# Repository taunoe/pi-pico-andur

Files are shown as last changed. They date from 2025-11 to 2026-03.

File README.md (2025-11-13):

# Pi Pico Andur

## Proto 0

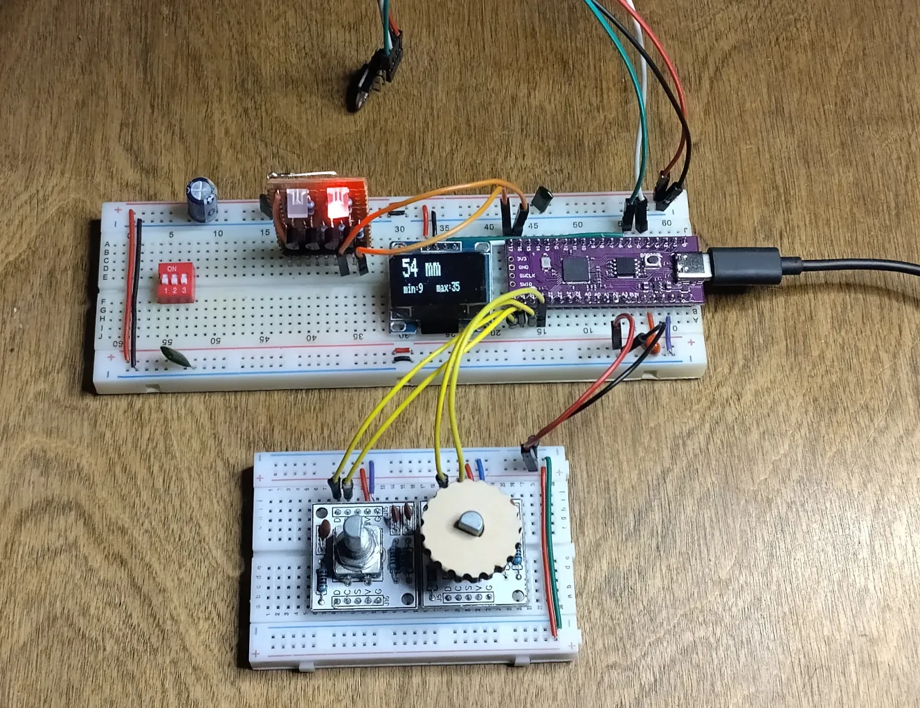
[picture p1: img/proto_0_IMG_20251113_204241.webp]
Pilt proto 0


- https://www.instagram.com/reel/DPMSu_giLpH/?utm_source=ig_web_copy_link&igsh=MzRlODBiNWFlZA==
- https://www.instagram.com/reel/DPefCeejA3R/?utm_source=ig_web_copy_link&igsh=MzRlODBiNWFlZA==

## Proto 1 Jupid

Pilt|Nimi    | m    | m   |Kood
----|--------|------|-----|----
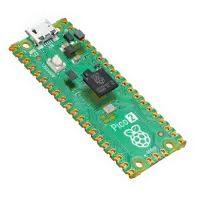
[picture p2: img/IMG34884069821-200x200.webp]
|RASPBERRY PI PICO 2| Cortex-M33| |SC1631
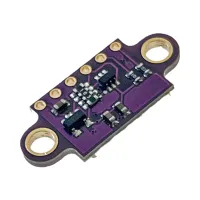
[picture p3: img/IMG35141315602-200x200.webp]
|ToF / Laser moodul| VL53L0X 3-5VDC| I2C, 0.05÷1.2m | OKYN220420-17
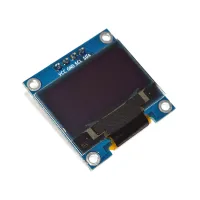
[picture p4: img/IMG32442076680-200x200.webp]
|OLED display| 0.96''| Sinine ja valge| OKY4020
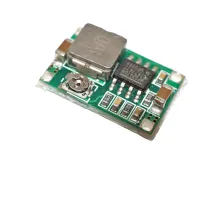
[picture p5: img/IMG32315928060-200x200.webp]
|Toitemoodul DC/DC| step-down |4.75..23V/1..17 3A|OKY3504-1
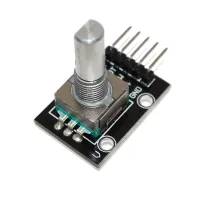
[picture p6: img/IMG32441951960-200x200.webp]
|Rotary Encoder|-|-| OKY3431
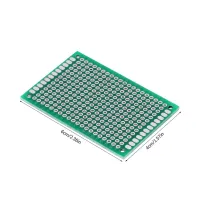
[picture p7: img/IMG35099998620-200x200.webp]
|Makettplaat| 40*60mm |-|OKY0001-1-4X6CM
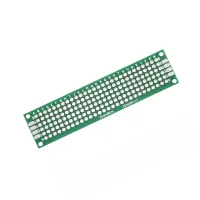
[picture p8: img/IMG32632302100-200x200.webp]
|Makettplaat| 20*80mm| kahepoolne| OKN426-8
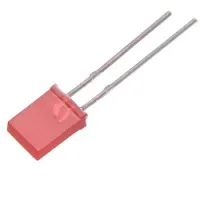
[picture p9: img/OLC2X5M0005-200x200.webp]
|LED punane matt| 2*5mm| 5mcd| OLC2X5M0005
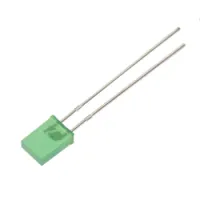
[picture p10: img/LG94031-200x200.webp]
|LED roheline matt| 2*5mm| 10mcd| LZ2X5M0010
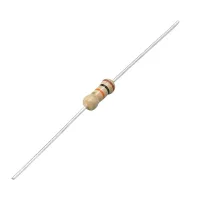
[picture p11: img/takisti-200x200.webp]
|Takisti | 470R | 1/4W| -
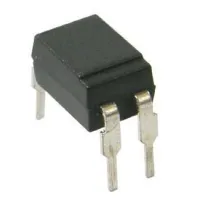
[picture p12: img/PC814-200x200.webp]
|Optron|EL817C |-| PC817
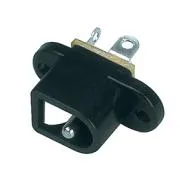
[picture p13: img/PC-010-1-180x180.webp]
|Toitepesa paneelile| 2.1/5.5mm| | PC-010
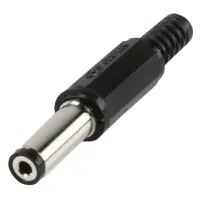
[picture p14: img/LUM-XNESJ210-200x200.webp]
|Pistik| 2.1/5.5mm| 14mm, plast| LUM-XNESJ210
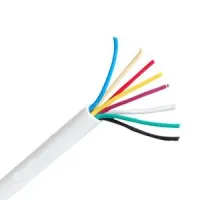
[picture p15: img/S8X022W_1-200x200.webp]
|Signalisatsioonikaabel|8x0.22mm2 |tinatatud Valge|S8X022W
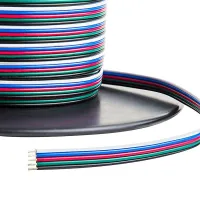
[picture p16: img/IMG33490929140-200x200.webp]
|Lintkaabel| 5*0.3mm2|-| LP05-RGBW
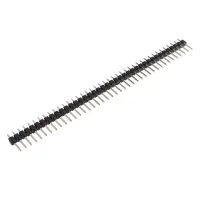
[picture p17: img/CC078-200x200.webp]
|Piikriba |1*40pin| 2.54mm|CC078
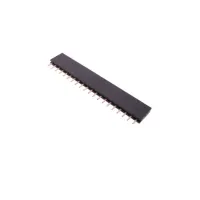
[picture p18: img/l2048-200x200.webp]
|Piikriba pesa plaadile| 1*20pin |2.54mm |L20420GS
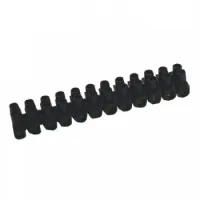
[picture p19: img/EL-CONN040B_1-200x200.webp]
|Kruviklemmliist| 12*2.5mm2| STCM-8471| EL-CONN040B
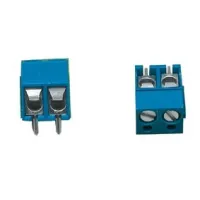
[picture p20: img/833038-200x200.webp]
|2-ne klemmliist pcb| 5.0mm| h=10mm 1.5mm2| TB-001LC
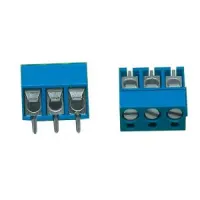
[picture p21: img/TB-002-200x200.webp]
|3-ne klemmiist. pcb| 5.0mm| h=12mm| TB-002
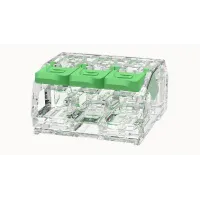
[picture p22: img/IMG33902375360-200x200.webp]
|Ühendusklemm 3-ne| kangiga avatav ja suletav|-| DGBSC-SG01/4-03P
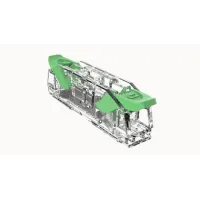
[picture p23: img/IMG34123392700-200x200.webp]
|Ühendusklemm 2-ne| kangiga| läbiv|DGBSC-SG02/4-01P
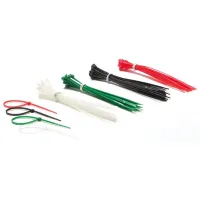
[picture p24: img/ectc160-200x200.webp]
|Kaablisideme komplekt| 160mm| Värvilised| ECTC160

Tauno Erik 2025

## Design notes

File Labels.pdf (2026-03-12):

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
GPIO1
XSHUT

VIN

SDA
SCL

GND

GPIO1

XSHUT

VIN

SDA
SCL

GND

GPIO1

XSHUT

VIN

SDA
SCL

GND

GPIO1

XSHUT

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
## SDA SCL GND VCC

Signal OUT | Sensor
| Sensor
| Sensor

+24V in

Signal OUT +24V in

Signal OUT

VCC

GND

SCL

SDA

+24V in

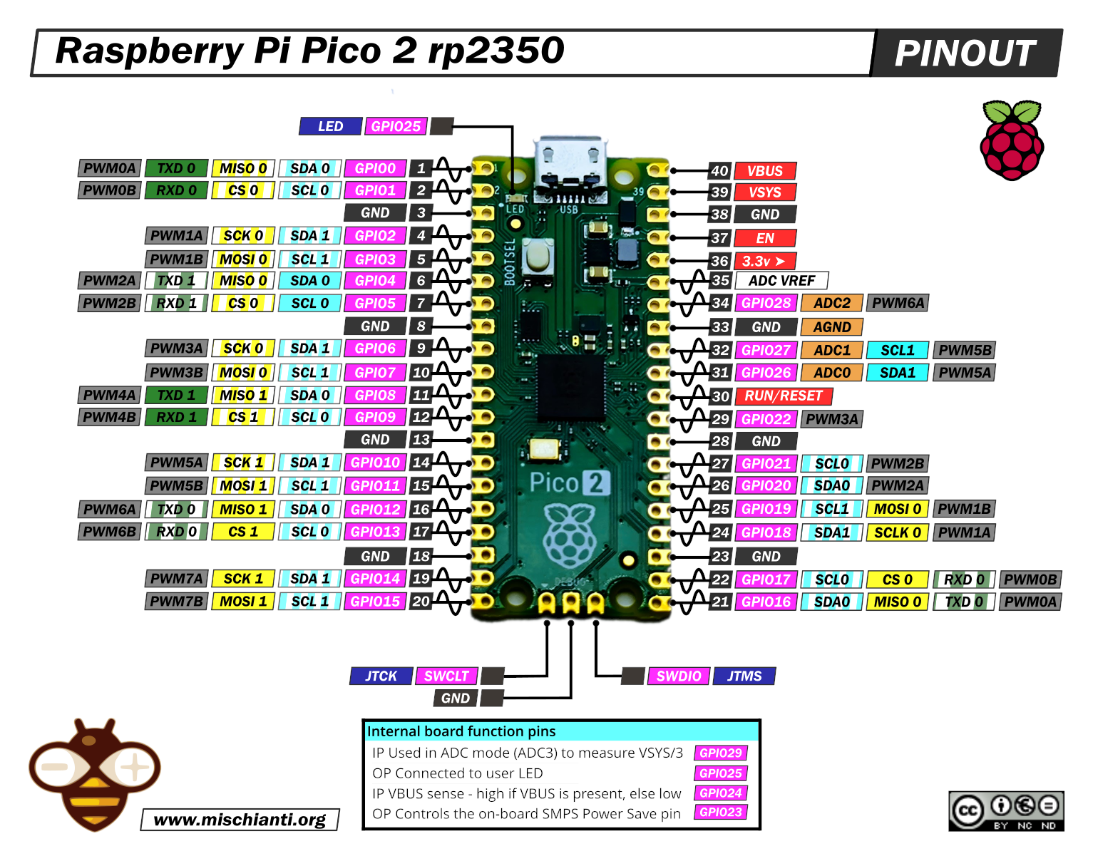
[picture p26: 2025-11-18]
datasheets/Raspberry-Pi-Pico-2-rp2350-pinout-mischianti.png

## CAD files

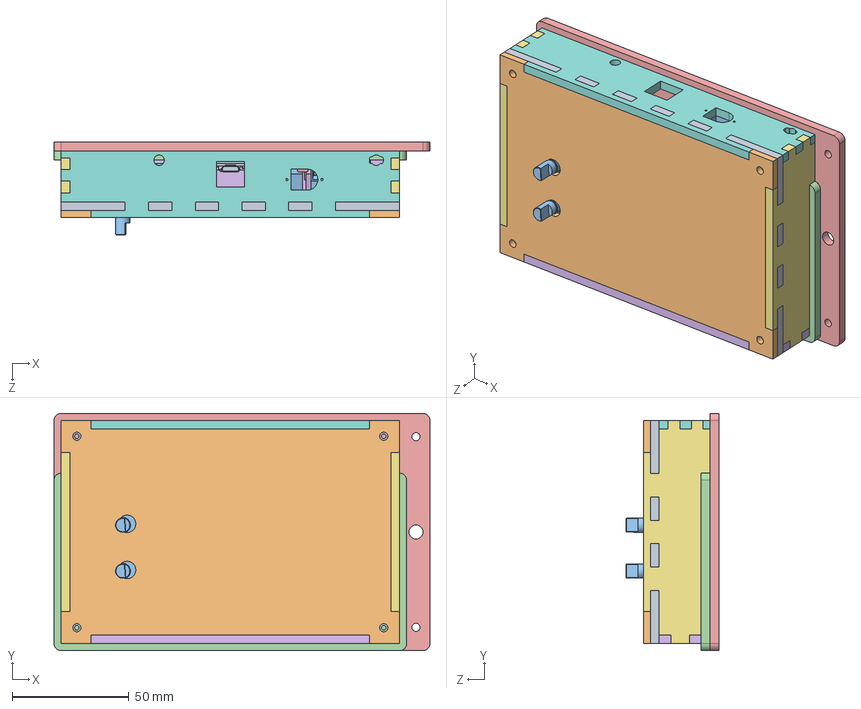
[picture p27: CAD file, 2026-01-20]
3d_models/v2_3.8mm/KOOS_v2.SLDASM
161.0 x 101.6 x 39.8 mm
RaspberryPi_Pico_W_Module_KiCad^RaspberryPi_Pico_W_pcb_KOOS_v2
D_DO-41_SOD81_P10.16mm_Horizontal^pcb_KOOS_v2 x 2
TerminalBlock_Phoenix_MKDS-1,5-2_1x02_P5.00mm_Horizontal^pcb_KOOS_v2 x 4
R_Axial_DIN0207_L6.3mm_D2.5mm_P10.16mm_Horizontal^pcb_KOOS_v2 x 6
DIP-4_W7.62mm^pcb_KOOS_v2 x 2
TerminalBlock_Phoenix_MKDS-1,5-3_1x03_P5.00mm_Horizontal^pcb_KOOS_v2 x 7
LED_Rectangular_W5.0mm_H2.0mm^pcb_KOOS_v2 x 2
TerminalBlock_Phoenix_PT-1,5-6-5.0-H_1x06_P5.00mm_Horizontal^pcb_KOOS_v2
pcb_PCB^pcb_KOOS_v2
OLED_IIC_096^KOOS_v2
Rotary-Encoder^KOOS_v2 x 2
v2_alusraam
v2_põhi
v2_külg_pikem
v2_külg_lühem x 2
v2_ülemine_raam
v2_pleks
v2_power_raam

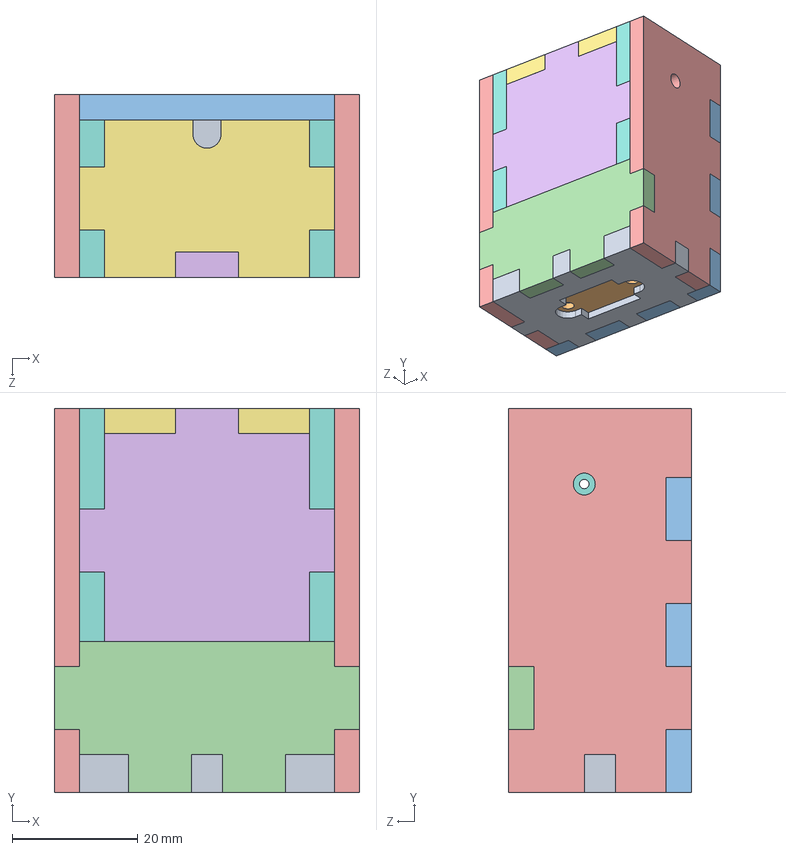
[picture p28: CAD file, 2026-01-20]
3d_models/v2_3.8mm/anduri_karp/v2_Anduri_karp.SLDASM
48.5 x 61.0 x 29.0 mm
v2_andur_esi
v2_andur_tof
v2_andur_alumine
v2_andur_pealmine
v2_andur_külg x 2
v2_andur_kaane_lagi
v2_andur_kaane_juhtmeauk
v2_andur_kaane_külg x 2

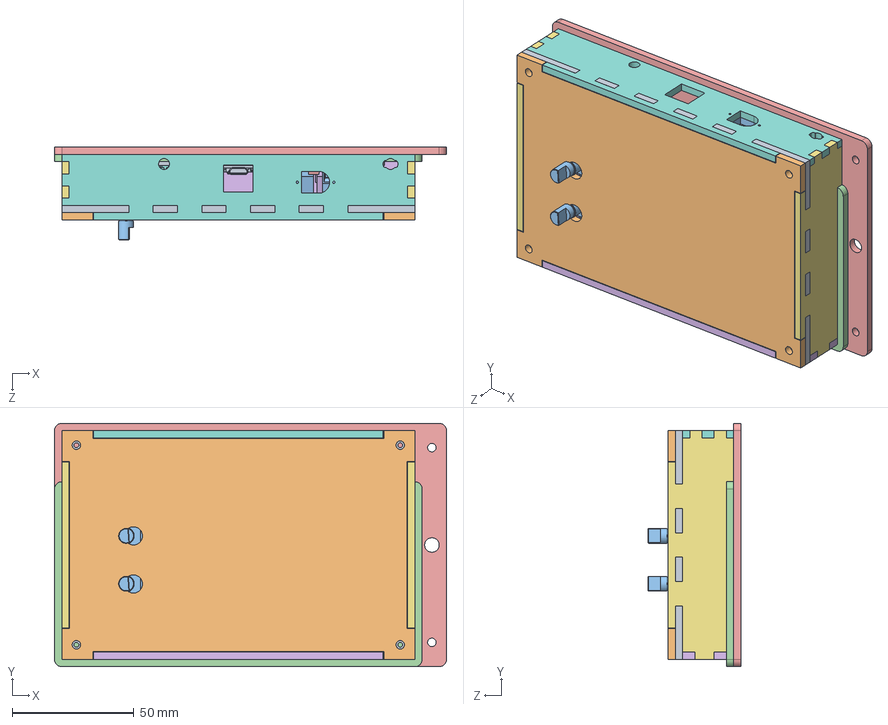
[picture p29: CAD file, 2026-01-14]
3d_models/v2/KOOS_v2.SLDASM
161.0 x 100.0 x 38.2 mm
RaspberryPi_Pico_W_Module_KiCad^RaspberryPi_Pico_W_pcb_KOOS_v2
D_DO-41_SOD81_P10.16mm_Horizontal^pcb_KOOS_v2 x 2
TerminalBlock_Phoenix_MKDS-1,5-2_1x02_P5.00mm_Horizontal^pcb_KOOS_v2 x 4
R_Axial_DIN0207_L6.3mm_D2.5mm_P10.16mm_Horizontal^pcb_KOOS_v2 x 6
DIP-4_W7.62mm^pcb_KOOS_v2 x 2
TerminalBlock_Phoenix_MKDS-1,5-3_1x03_P5.00mm_Horizontal^pcb_KOOS_v2 x 7
LED_Rectangular_W5.0mm_H2.0mm^pcb_KOOS_v2 x 2
TerminalBlock_Phoenix_PT-1,5-6-5.0-H_1x06_P5.00mm_Horizontal^pcb_KOOS_v2
pcb_PCB^pcb_KOOS_v2
OLED_IIC_096^KOOS_v2
Rotary-Encoder^KOOS_v2 x 2
v2_alusraam
v2_põhi
v2_külg_pikem
v2_külg_lühem x 2
v2_külg_pikem_avadega
v2_ülemine_raam
v2_pleks
v2_power_raam

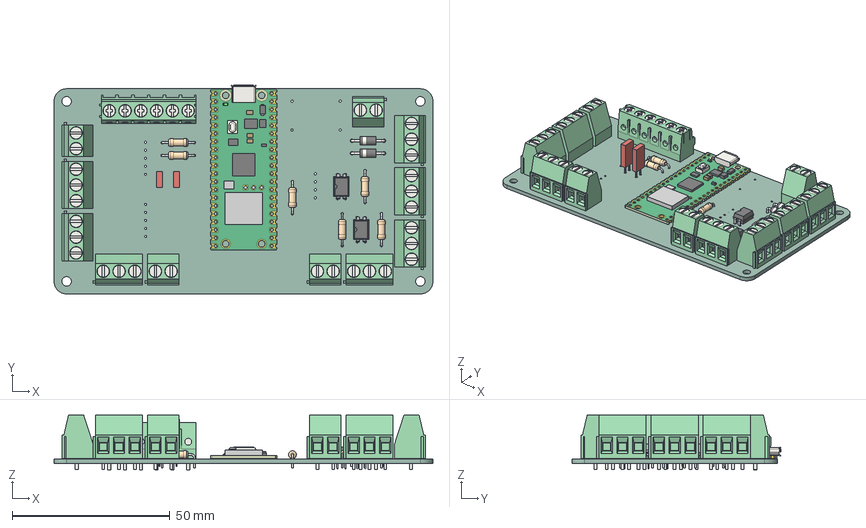
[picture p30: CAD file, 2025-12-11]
3d_models/pcb.step
120.0 x 66.2 x 17.4 mm
D_DO-41_SOD81_P10.16mm_Horizontal x 2
TerminalBlock_Phoenix_MKDS-1,5-2_1x02_P5.00mm_Horizontal x 4
R_Axial_DIN0207_L6.3mm_D2.5mm_P10.16mm_Horizontal x 6
DIP-4_W7.62mm x 2
TerminalBlock_Phoenix_MKDS-1,5-3_1x03_P5.00mm_Horizontal x 7
RaspberryPi_Pico_W_Module_KiCad
LED_Rectangular_W5.0mm_H2.0mm x 2
TerminalBlock_Phoenix_PT-1,5-6-5.0-H_1x06_P5.00mm_Horizontal
pcb_PCB

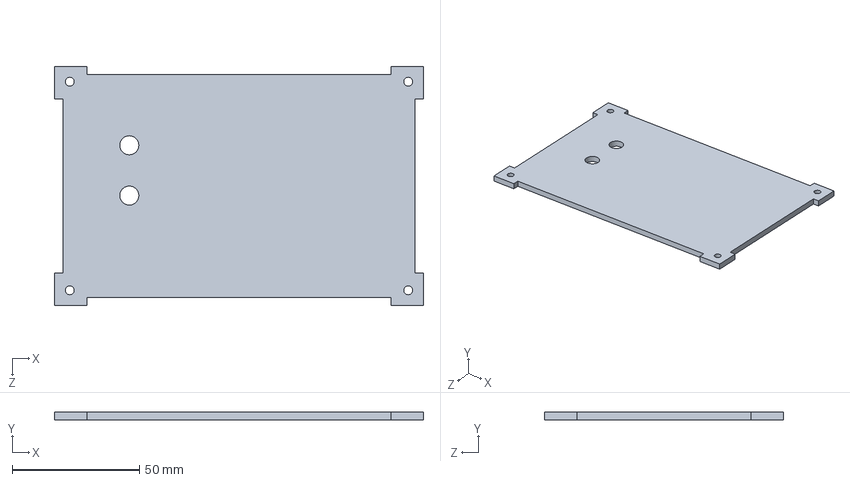
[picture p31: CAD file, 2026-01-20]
3d_models/v2/v2_pleks.SLDPRT
145.0 x 3.00 x 94.0 mm

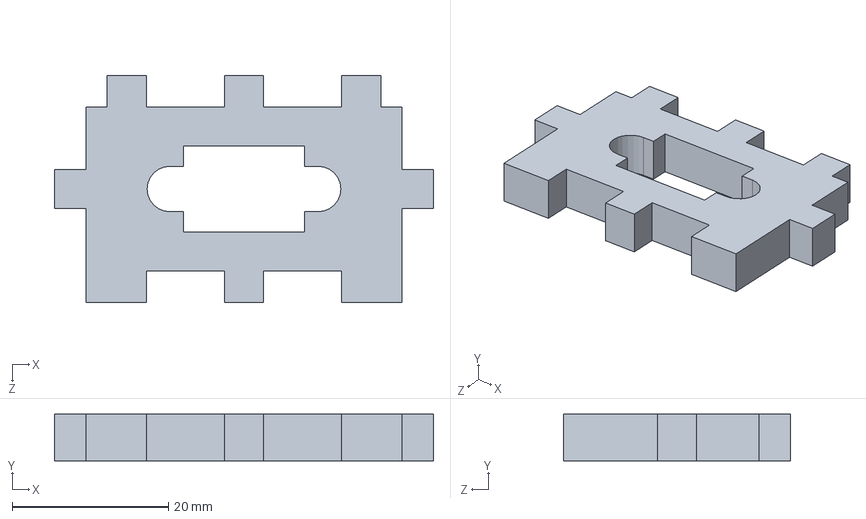
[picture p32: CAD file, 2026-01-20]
3d_models/v2_3.8mm/anduri_karp/v2_andur_esi.SLDPRT
48.5 x 6.00 x 29.0 mm

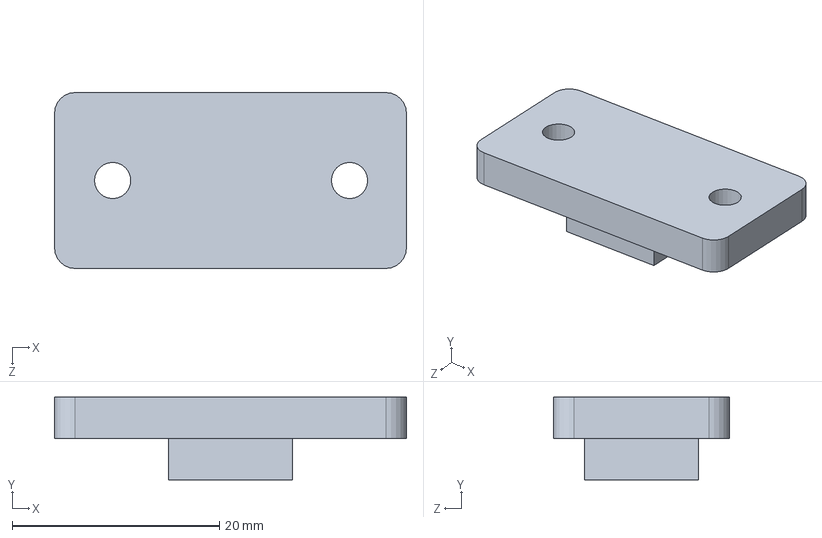
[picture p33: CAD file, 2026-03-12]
3d_models/v2_3.8mm/v2_usb_kork.SLDPRT
34.0 x 8.00 x 17.0 mm

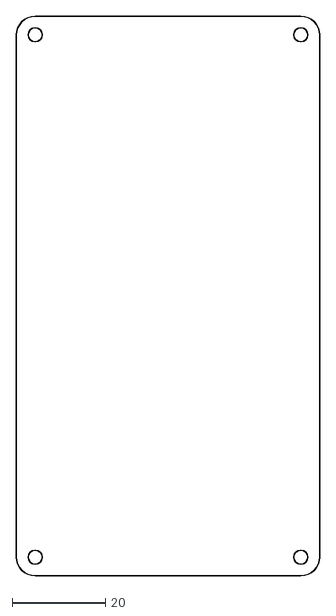
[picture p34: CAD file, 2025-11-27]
KiCad/pcb/piirjoon.dxf
65.0 x 120.0

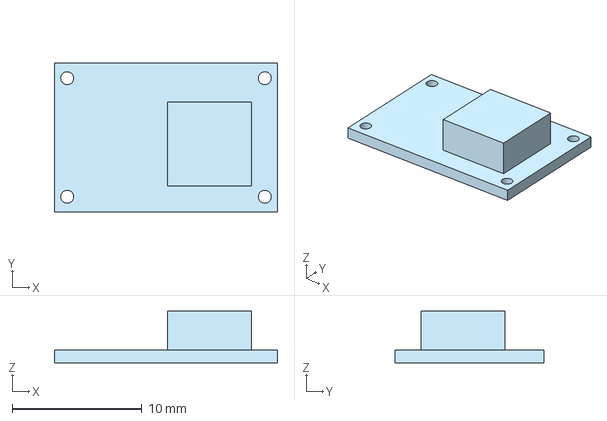
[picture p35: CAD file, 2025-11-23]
3d_models/power.step
17.2 x 11.5 x 4.00 mm

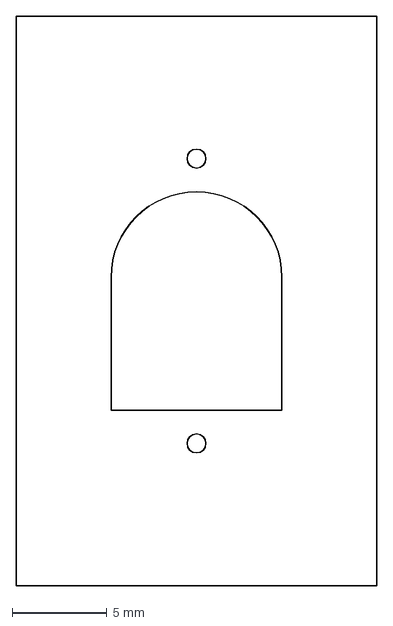
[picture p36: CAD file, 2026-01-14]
3d_models/v2/v2_power_raam.DXF
19.0 x 30.0 mm

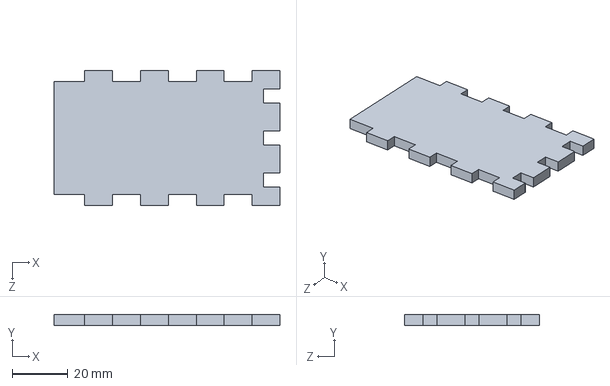
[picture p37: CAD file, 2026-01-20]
3d_models/v2_3.8mm/anduri_karp/v2_andur_alumine.SLDPRT
81.0 x 4.00 x 48.5 mm

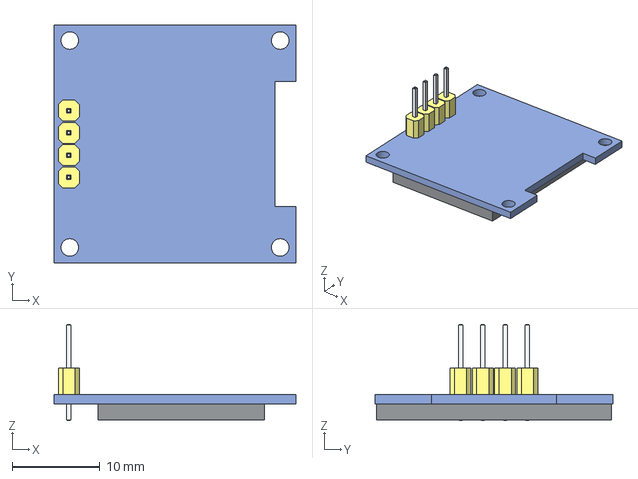
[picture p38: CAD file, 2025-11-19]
3d_models/OLED_IIC_096.step
27.6 x 27.2 x 11.0 mm

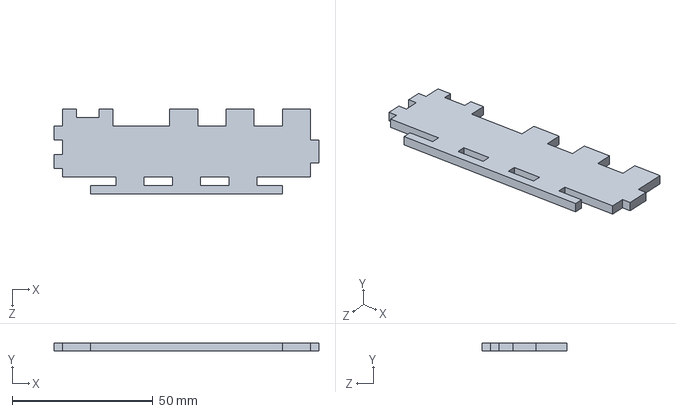
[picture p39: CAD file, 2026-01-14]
3d_models/v2/v2_külg_lühem.SLDPRT
94.0 x 3.00 x 30.0 mm

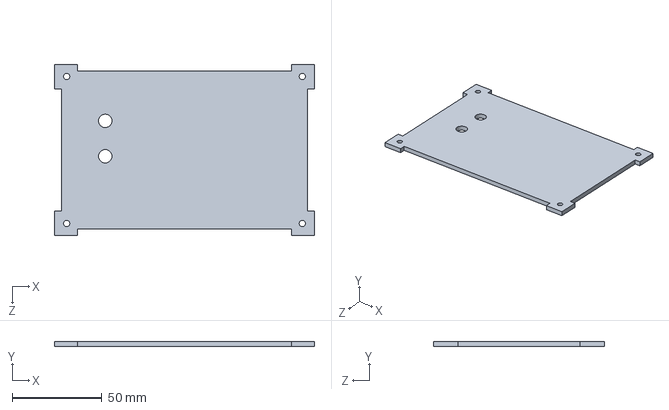
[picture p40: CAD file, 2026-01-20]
3d_models/v2_3.8mm/v2_pleks.SLDPRT
145.0 x 3.00 x 95.6 mm

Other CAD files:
3d_models/Rotary-Encoder.step
3d_models/v2/v2_ülemine_raam.SLDPRT
3d_models/v2_3.8mm/anduri_karp/v2_andur_tof.SLDPRT
3d_models/v2_3.8mm/v2_põhi.SLDPRT
3d_models/v1/Anduri_karp.SLDASM
3d_models/v1/KOOS.SLDASM
3d_models/v1/PCB.DXF
3d_models/v1/andur_alumine.DXF
3d_models/v1/andur_alumine.SLDPRT
3d_models/v1/andur_esi.DXF
3d_models/v1/andur_esi.SLDPRT
3d_models/v1/andur_kaane_juhtmeauk.DXF
3d_models/v1/andur_kaane_juhtmeauk.SLDPRT
3d_models/v1/andur_kaane_külg.DXF
3d_models/v1/andur_kaane_külg.SLDPRT
3d_models/v1/andur_kaane_lagi.DXF
3d_models/v1/andur_kaane_lagi.SLDPRT
3d_models/v1/andur_külg.DXF
3d_models/v1/andur_külg.SLDPRT
3d_models/v1/andur_pealmine.DXF
3d_models/v1/andur_pealmine.SLDPRT
3d_models/v1/andur_tof.SLDPRT
3d_models/v1/ekraani_kinnitus_1.DXF
3d_models/v1/ekraani_kinnitus_1.SLDPRT
3d_models/v1/hing_1.DXF
3d_models/v1/hing_1.SLDPRT
3d_models/v1/kinnitus_plaat.DXF
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

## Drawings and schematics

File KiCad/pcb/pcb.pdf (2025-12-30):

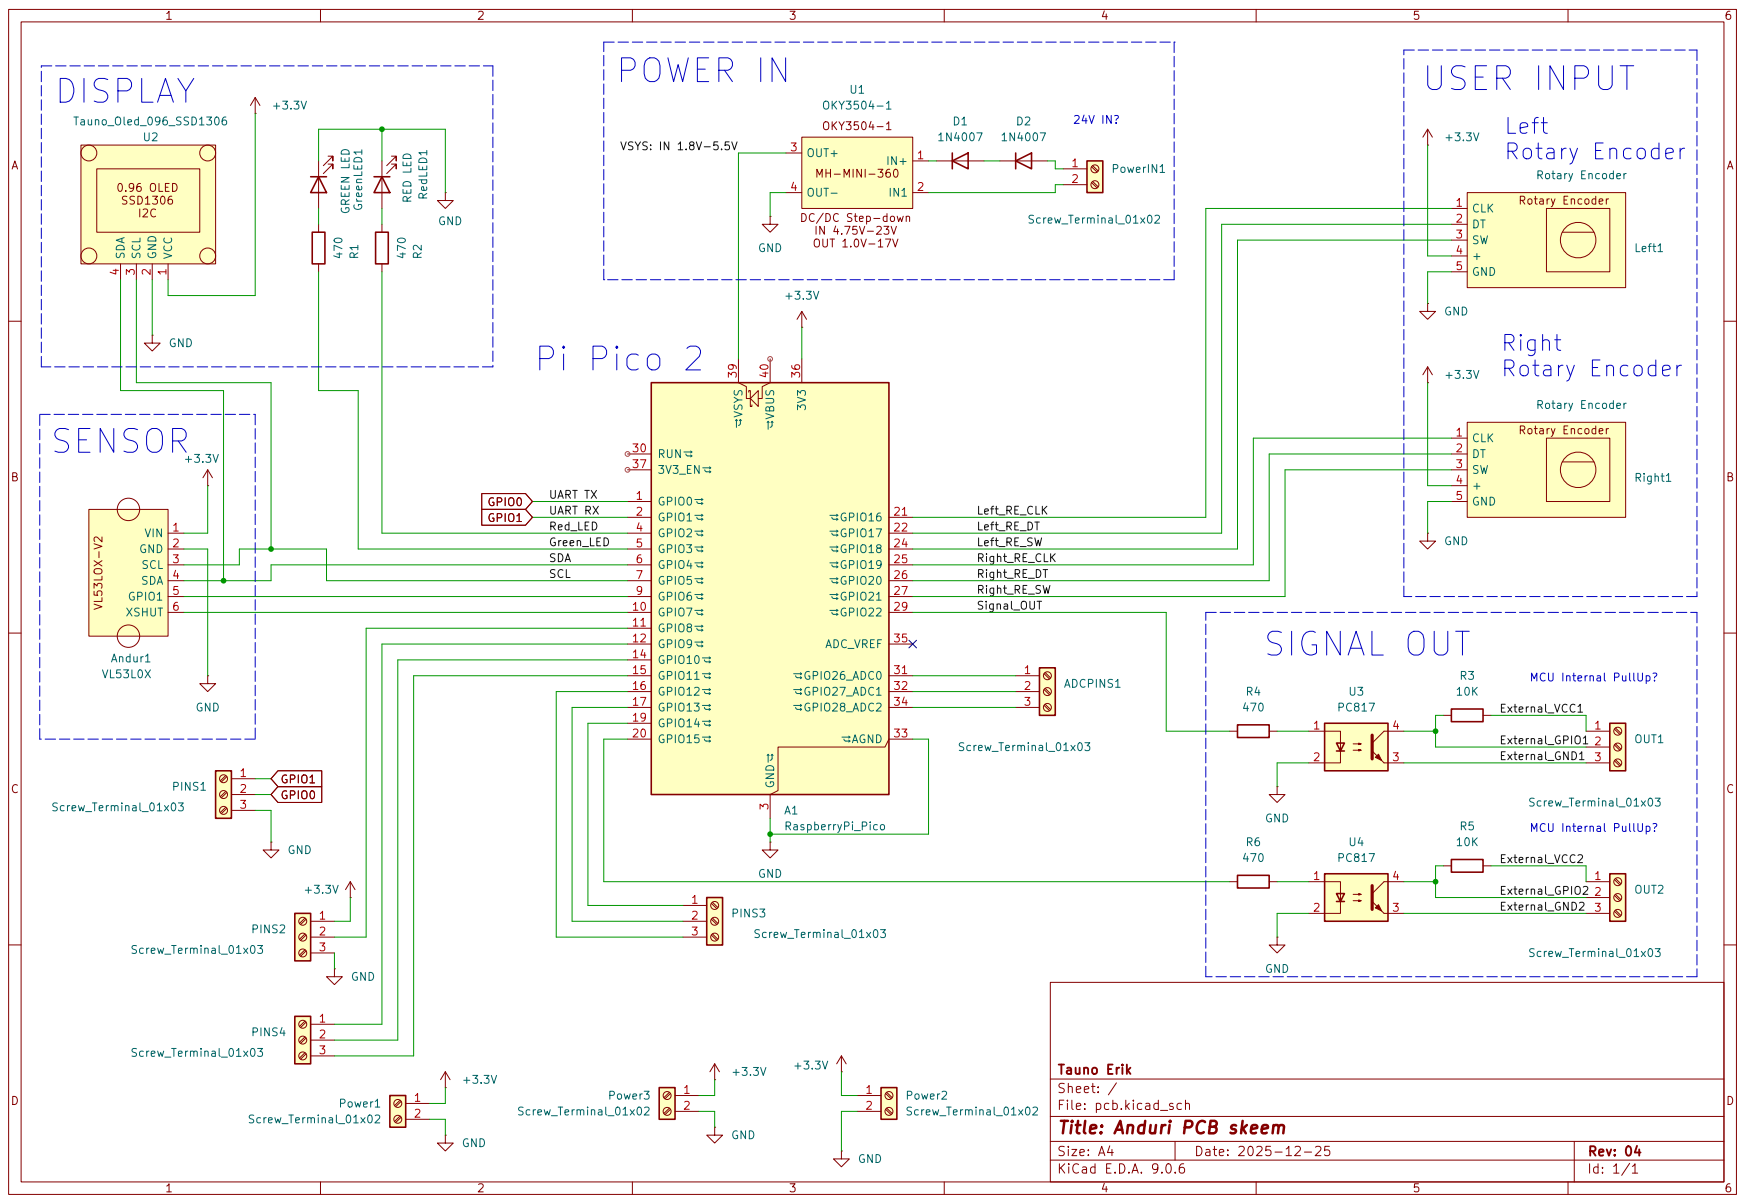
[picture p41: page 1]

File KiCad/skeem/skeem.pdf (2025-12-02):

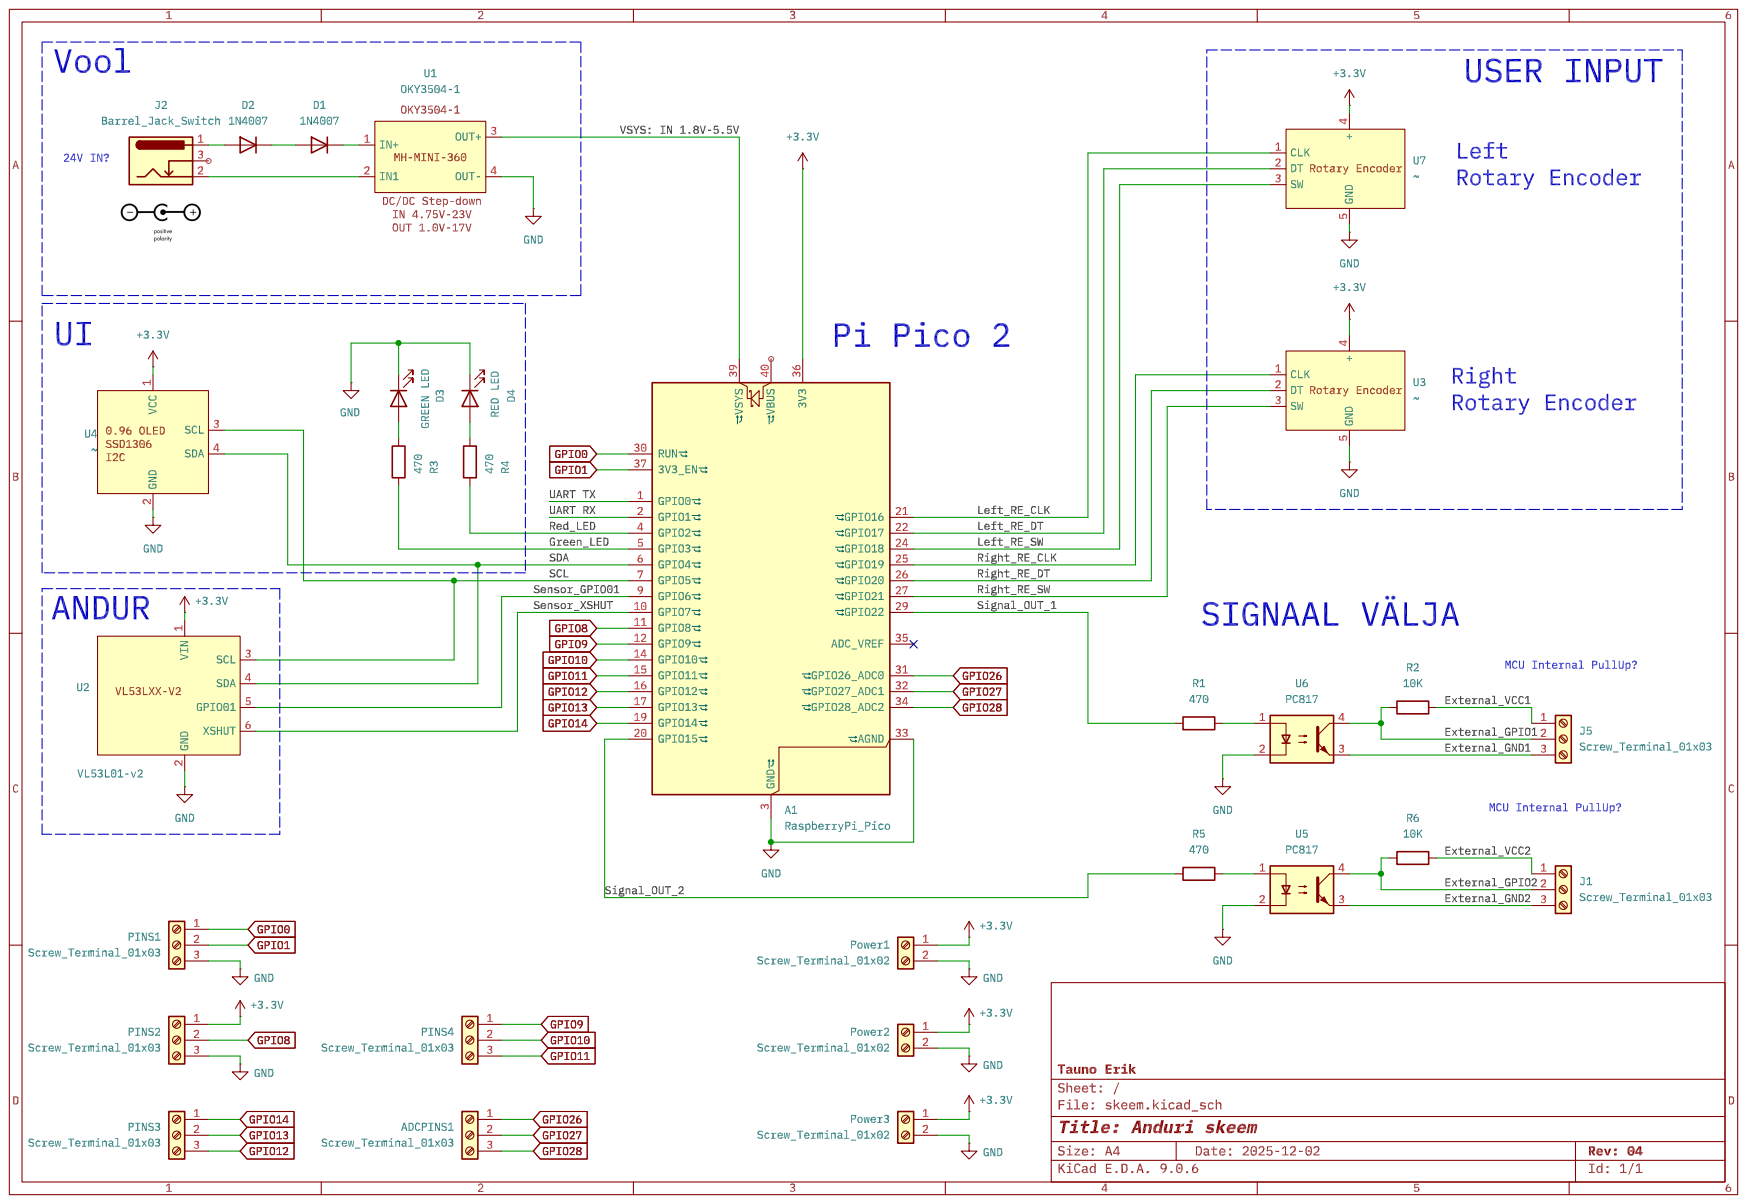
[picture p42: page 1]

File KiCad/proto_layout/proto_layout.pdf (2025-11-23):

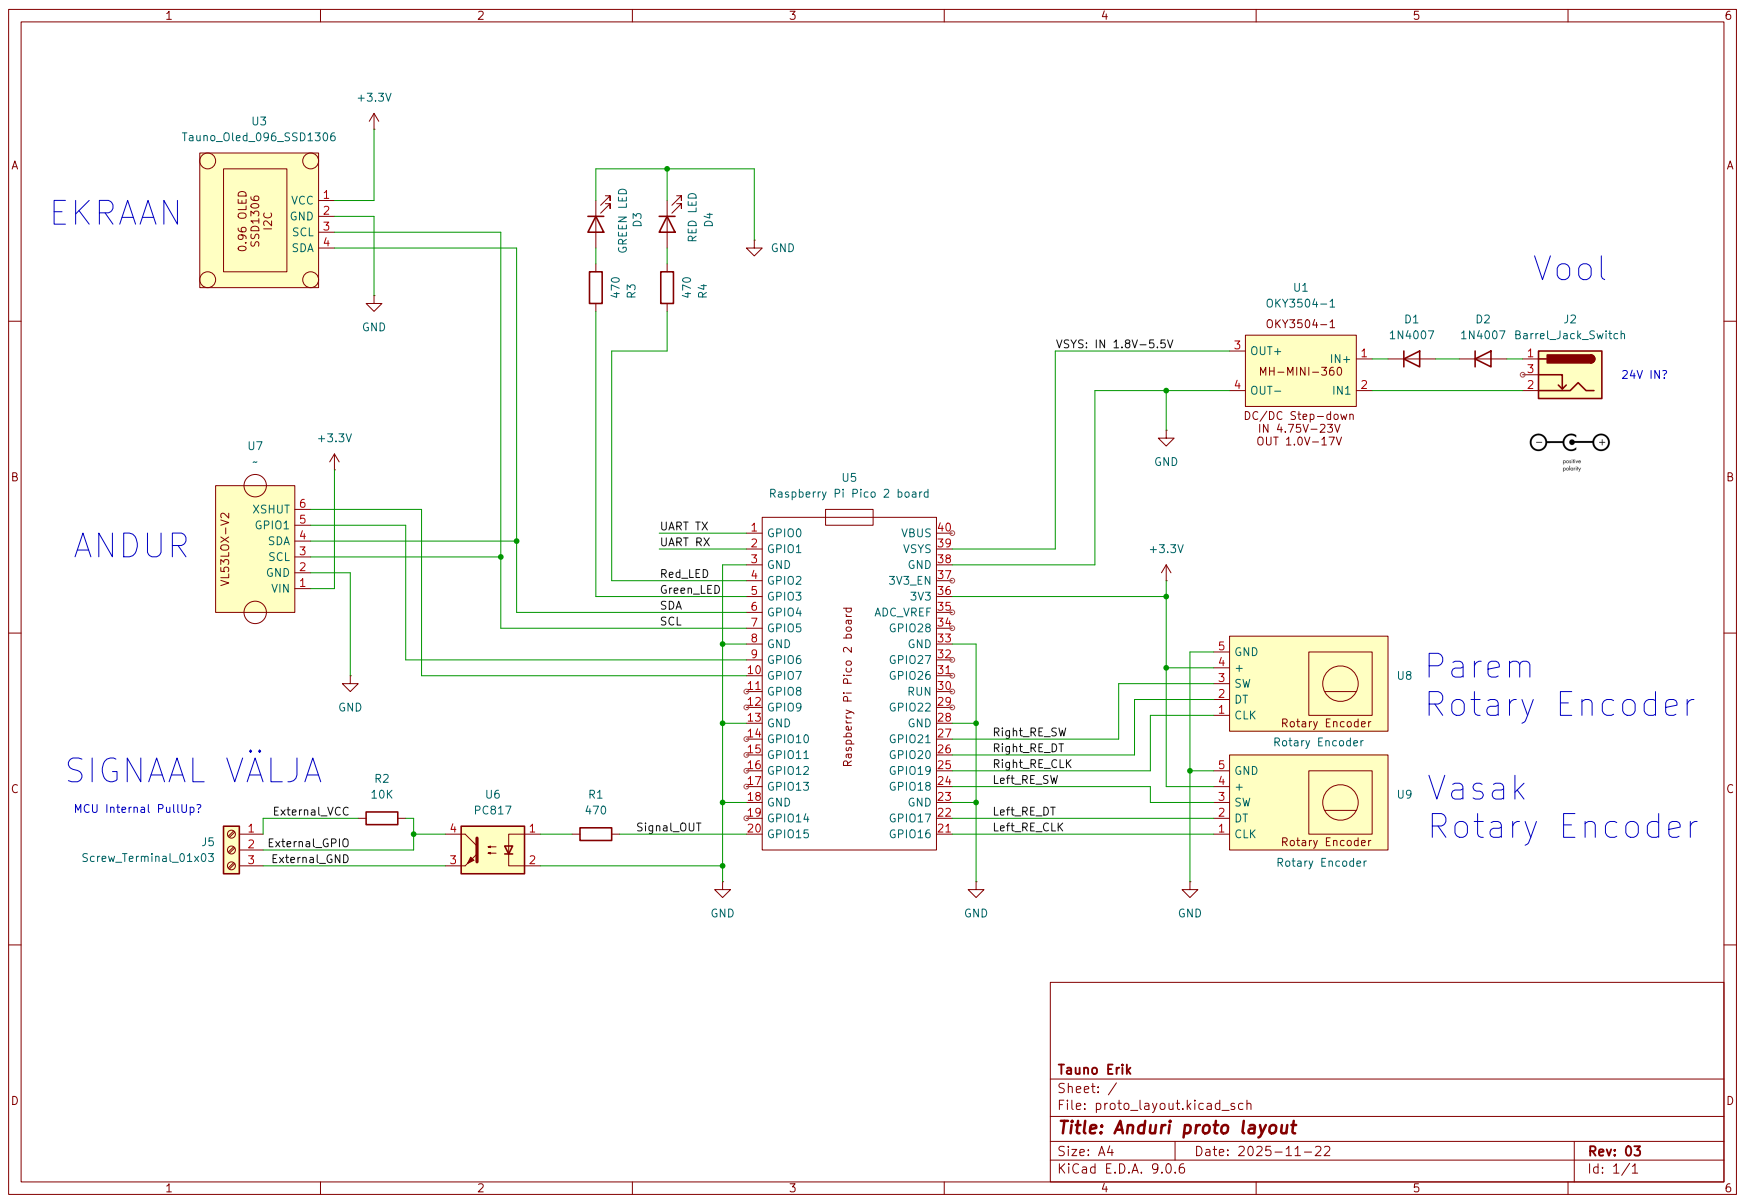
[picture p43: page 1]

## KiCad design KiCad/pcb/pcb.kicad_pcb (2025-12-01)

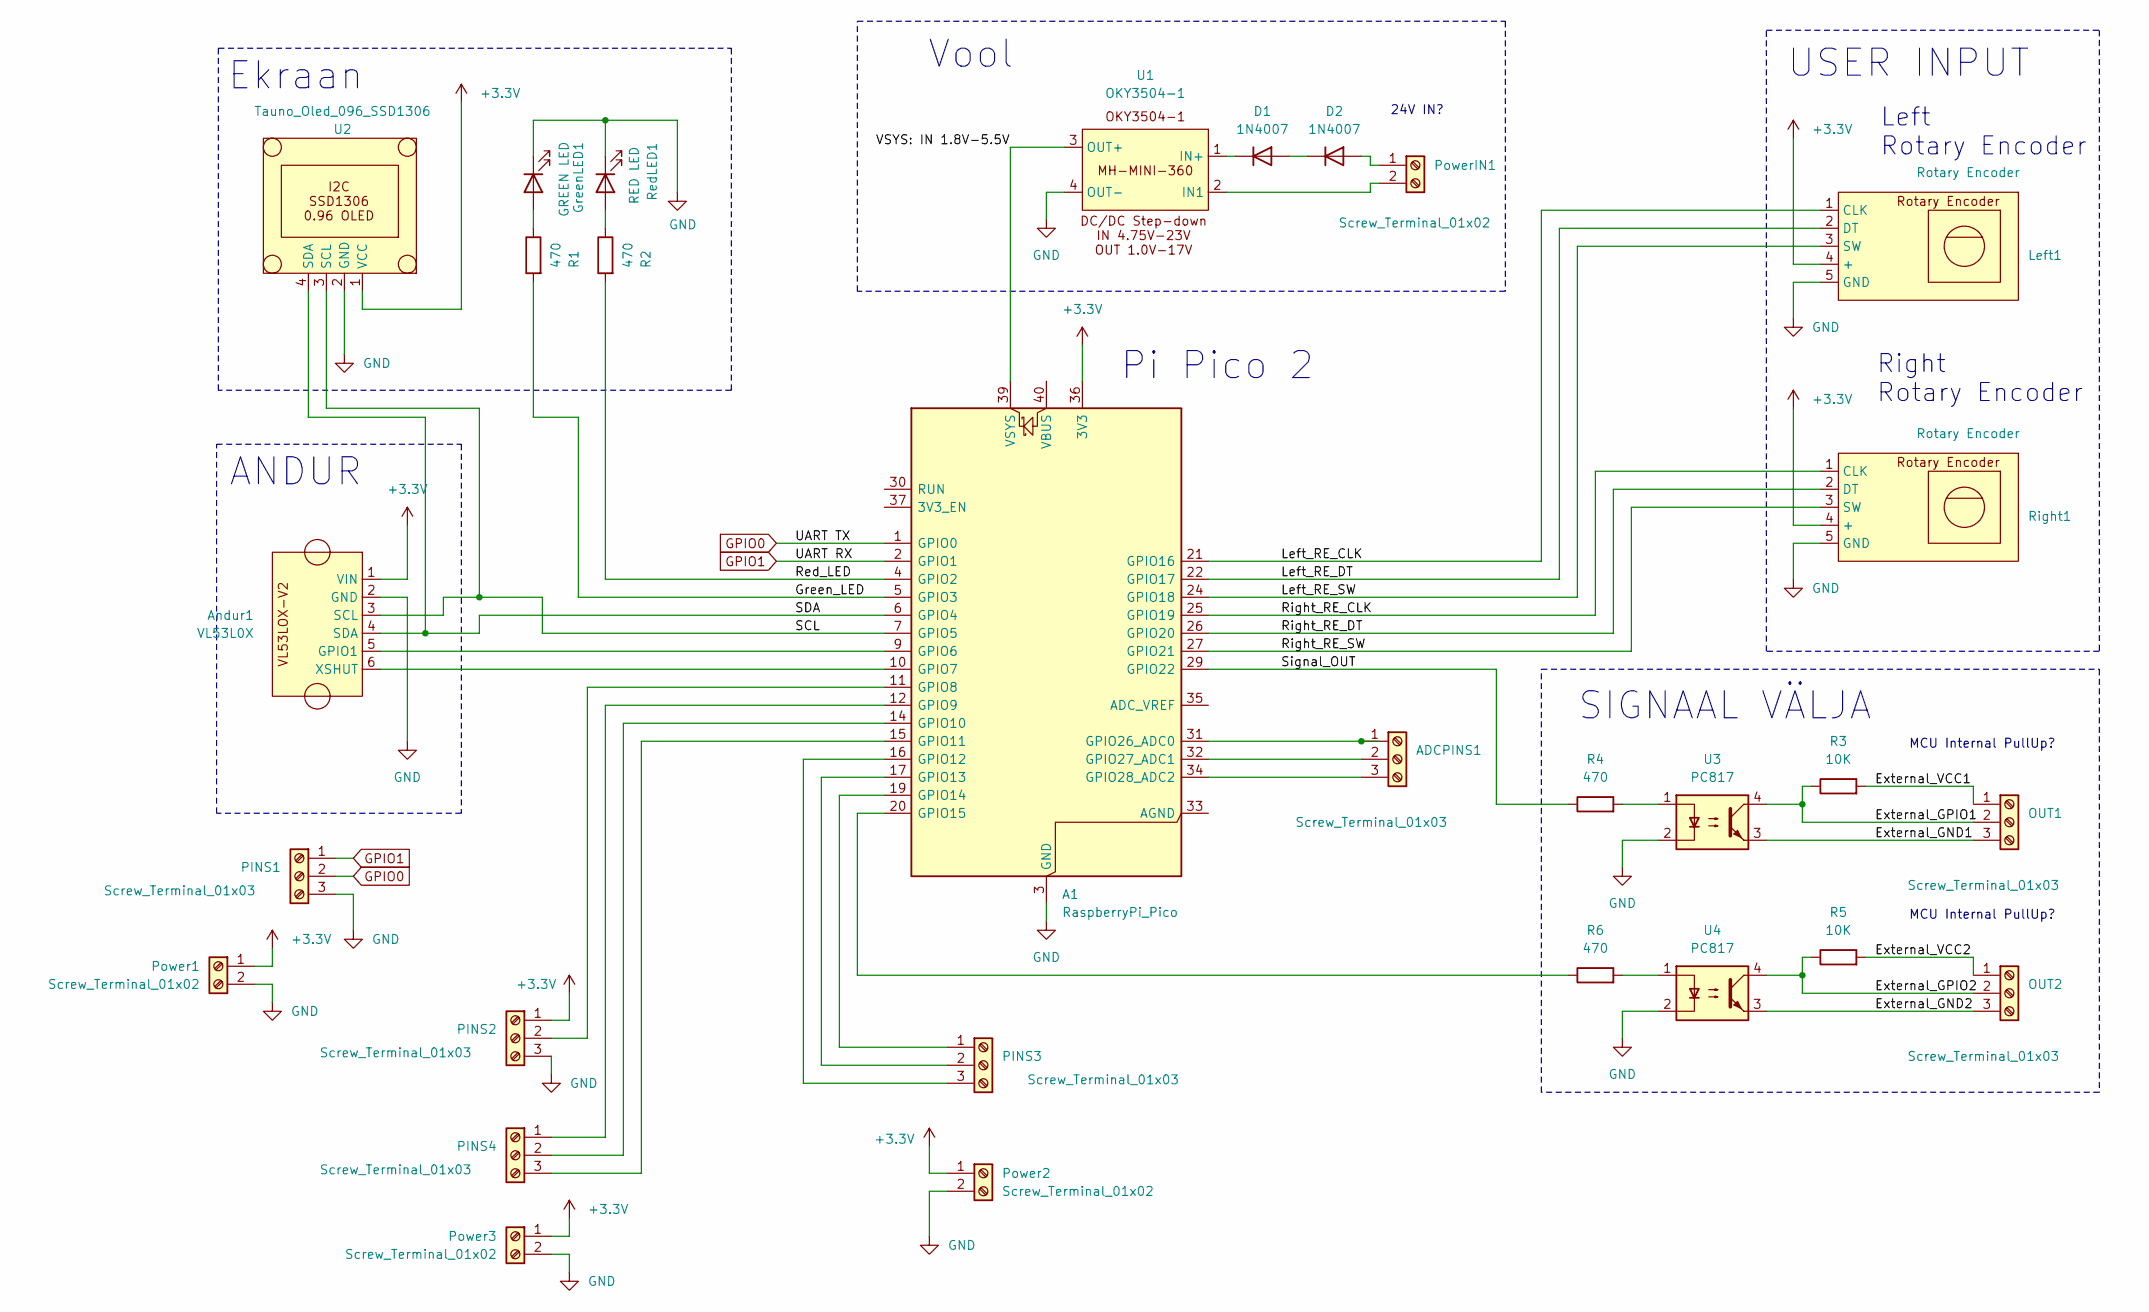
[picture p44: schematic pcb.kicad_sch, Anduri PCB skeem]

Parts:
A1: RaspberryPi_Pico; RaspberryPi_Pico_W_SMD_HandSolder
ADCPINS1: Screw_Terminal_01x03; TerminalBlock_MaiXu_MX126-5.0-03P_1x03_P5.00mm
Andur1: VL53L0X; TerminalBlock_MaiXu_MX126-5.0-06P_1x06_P5.00mm
D1, D2: 1N4007; D_DO-41_SOD81_P10.16mm_Horizontal
GreenLED1: GREEN LED; LED_Rectangular_W5.0mm_H2.0mm
Left1: Rotary Encoder; Tauno_Rotary_Encoder
OUT1, OUT2: Screw_Terminal_01x03; TerminalBlock_MaiXu_MX126-5.0-03P_1x03_P5.00mm
PINS1, PINS2, PINS3, PINS4: Screw_Terminal_01x03; TerminalBlock_MaiXu_MX126-5.0-03P_1x03_P5.00mm
Power1, Power2, Power3: Screw_Terminal_01x02; TerminalBlock_MaiXu_MX126-5.0-02P_1x02_P5.00mm
PowerIN1: Screw_Terminal_01x02; TerminalBlock_MaiXu_MX126-5.0-02P_1x02_P5.00mm
R1, R2, R4, R6: 470; R_Axial_DIN0207_L6.3mm_D2.5mm_P10.16mm_Horizontal
R3, R5: 10K; R_Axial_DIN0207_L6.3mm_D2.5mm_P10.16mm_Horizontal
RedLED1: RED LED; LED_Rectangular_W5.0mm_H2.0mm
Right1: Rotary Encoder; Tauno_Rotary_Encoder
U1: OKY3504-1; Tauno_OKY3504
U2: Tauno_Oled_096_SSD1306; Tauno_OLED_ssd1306
U3, U4: PC817; DIP-4_W7.62mm

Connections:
+3.3V: A1.36 (3V3), Andur1.1 (VIN), Left1.4 (+), PINS2.1, Power1.1, Power2.1, Power3.1, Right1.4 (+), U2.1 (VCC)
/External_GND1: OUT1.3, U3.3
/External_GND2: OUT2.3, U4.3
/External_GPIO1: OUT1.2, R3.1, U3.4
/External_GPIO2: OUT2.2, R5.1, U4.4
/External_VCC1: OUT1.1, R3.2
/External_VCC2: OUT2.1, R5.2
/Green_LED: A1.5 (GPIO3), R1.2
/Left_RE_CLK: A1.21 (GPIO16), Left1.1 (CLK)
/Left_RE_DT: A1.22 (GPIO17), Left1.2 (DT)
/Left_RE_SW: A1.24 (GPIO18), Left1.3 (SW)
/Red_LED: A1.4 (GPIO2), R2.2
/Right_RE_CLK: A1.25 (GPIO19), Right1.1 (CLK)
/Right_RE_DT: A1.26 (GPIO20), Right1.2 (DT)
/Right_RE_SW: A1.27 (GPIO21), Right1.3 (SW)
/SCL: A1.7 (GPIO5), Andur1.3 (SCL), U2.3 (SCL)
/SDA: A1.6 (GPIO4), Andur1.4 (SDA), U2.4 (SDA)
/Signal_OUT: A1.29 (GPIO22), R4.1
/VSYS: IN 1.8V-5.5V: A1.39 (VSYS), U1.3 (OUT+)
GND: A1.3 (GND), A1.8 (GND), A1.13 (GND), A1.18 (GND), A1.23 (GND), A1.28 (GND), A1.38 (GND), Andur1.2 (GND), GreenLED1.1 (K), Left1.5 (GND), PINS1.3, PINS2.3, Power1.2, Power2.2, Power3.2, RedLED1.1 (K), Right1.5 (GND), U1.4 (OUT-), U2.2 (GND), U3.2, U4.2
GPIO0: A1.1 (GPIO0), PINS1.2
GPIO1: A1.2 (GPIO1), PINS1.1
unnamed: A1.9 (GPIO6), Andur1.5 (GPIO1)
unnamed: A1.10 (GPIO7), Andur1.6 (XSHUT)
unnamed: A1.11 (GPIO8), PINS2.2
unnamed: A1.12 (GPIO9), PINS4.1
unnamed: A1.14 (GPIO10), PINS4.2
unnamed: A1.15 (GPIO11), PINS4.3
unnamed: A1.16 (GPIO12), PINS3.3
unnamed: A1.17 (GPIO13), PINS3.2
unnamed: A1.19 (GPIO14), PINS3.1
unnamed: A1.20 (GPIO15), R6.1
unnamed: A1.31 (GPIO26_ADC0), ADCPINS1.1
unnamed: A1.32 (GPIO27_ADC1), ADCPINS1.2
unnamed: A1.34 (GPIO28_ADC2), ADCPINS1.3
unnamed: D1.2 (A), D2.1 (K)
unnamed: D1.1 (K), U1.1 (IN+)
unnamed: D2.2 (A), PowerIN1.1
unnamed: GreenLED1.2 (A), R1.1
unnamed: PowerIN1.2, U1.2 (IN1)
unnamed: R4.2, U3.1
unnamed: R6.2, U4.1
unnamed: R2.1, RedLED1.2 (A)

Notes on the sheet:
Right Rotary Encoder
Ekraan
Vool
ANDUR
MCU Internal PullUp?
Pi Pico 2
SIGNAAL VÄLJA
USER INPUT
24V IN?
Left Rotary Encoder

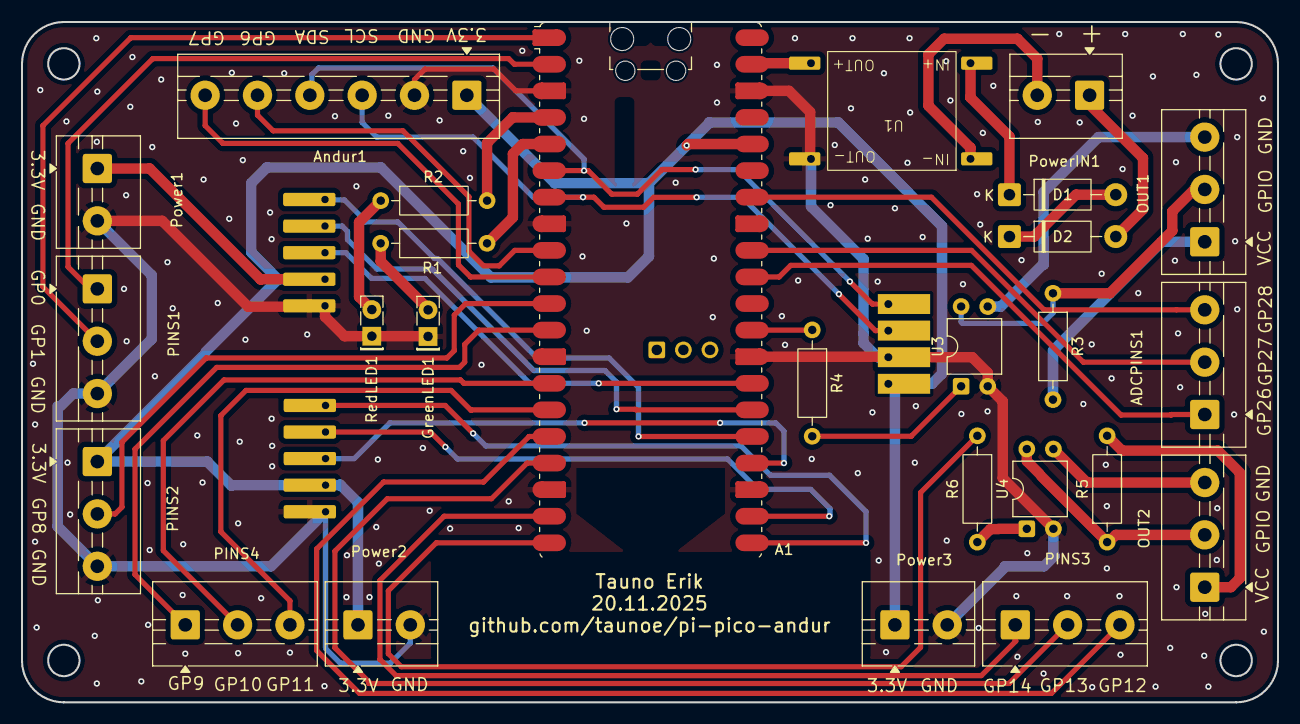
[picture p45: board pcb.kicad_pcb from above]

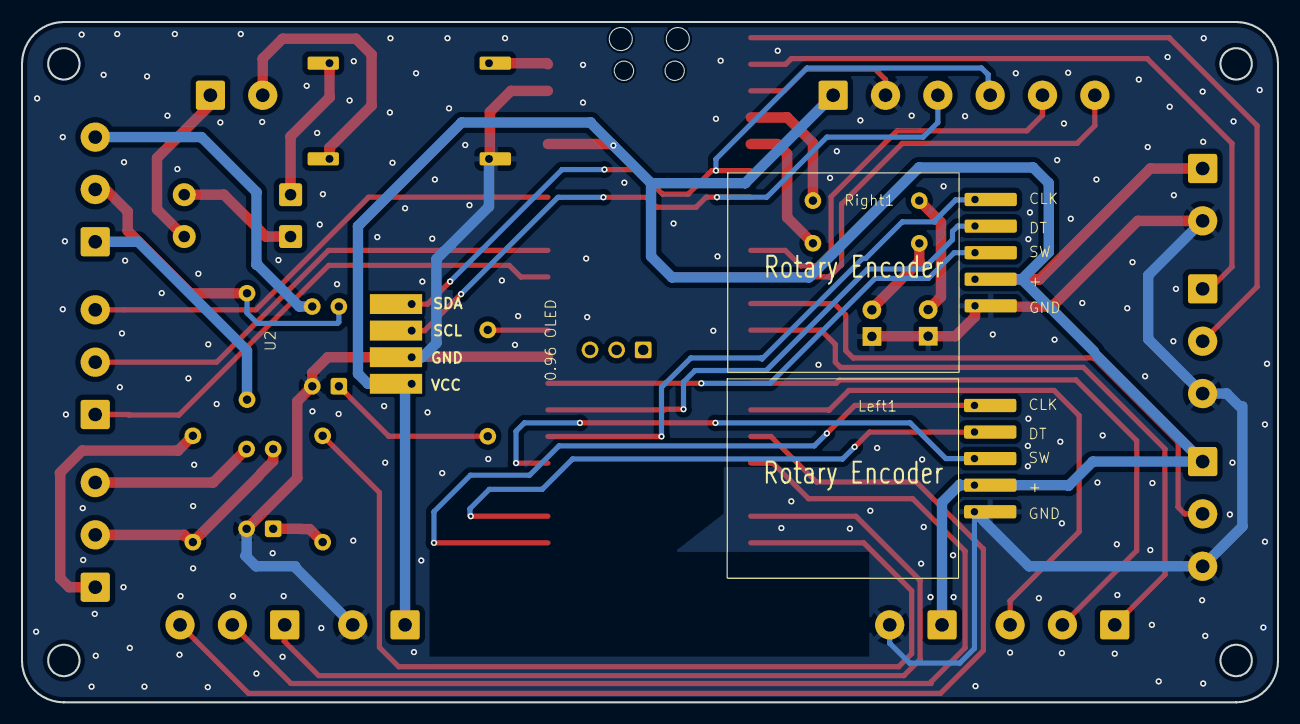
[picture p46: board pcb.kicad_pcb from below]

Board: 2 copper layers, 120.0 x 65.0 mm, 29 parts (3 on the bottom side), 43 nets.

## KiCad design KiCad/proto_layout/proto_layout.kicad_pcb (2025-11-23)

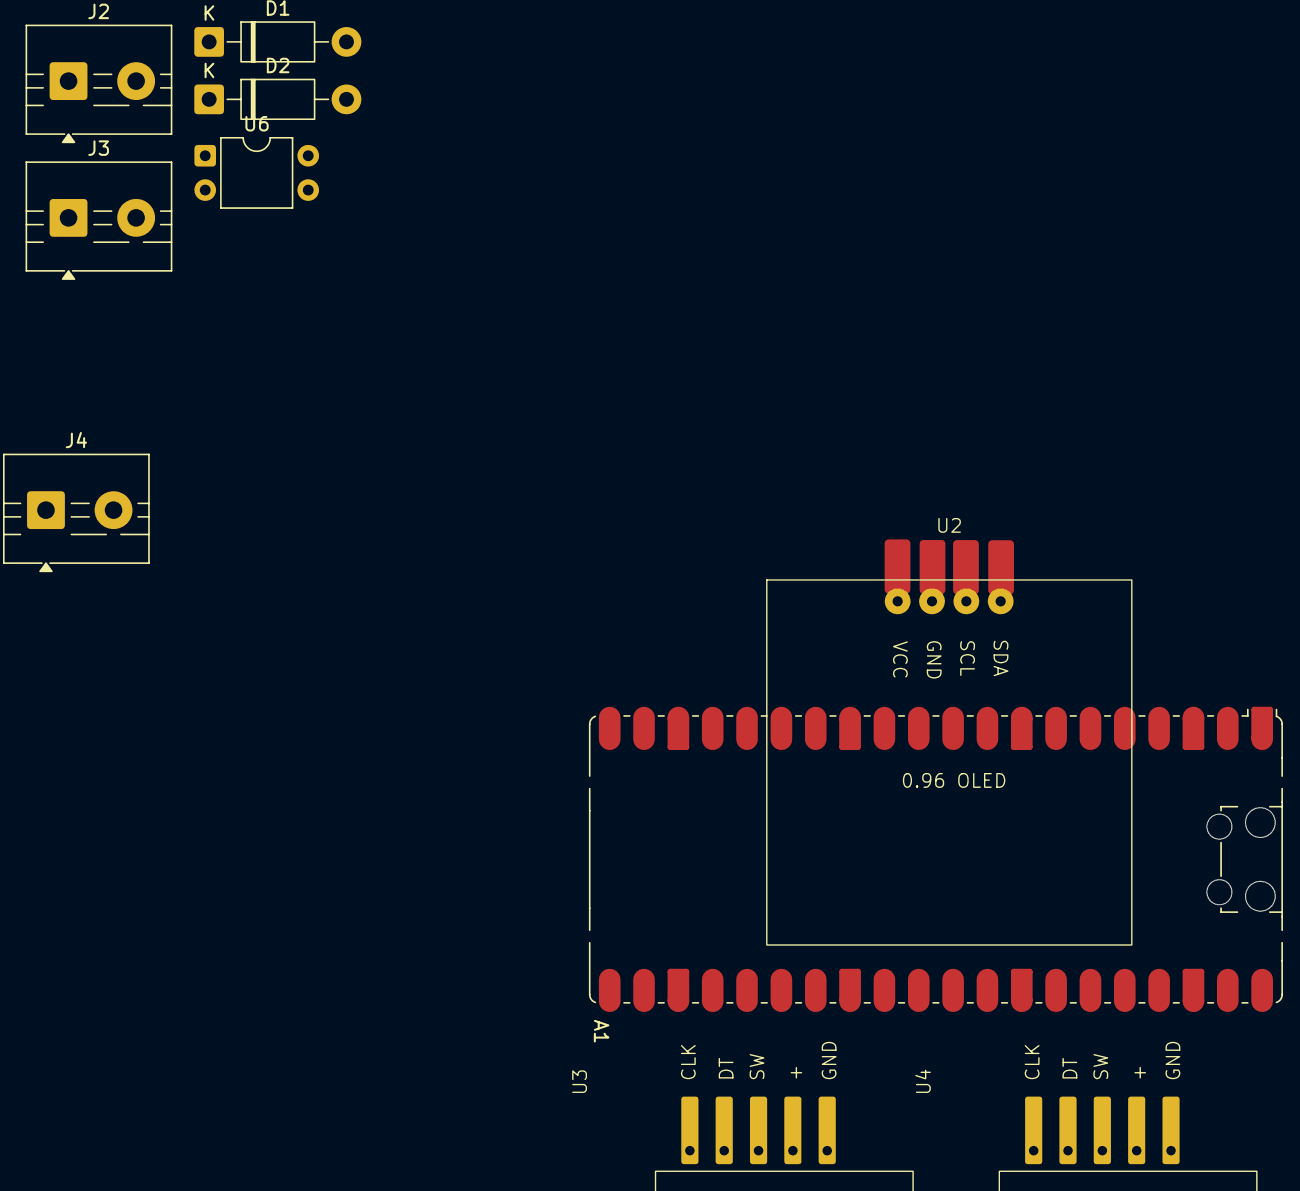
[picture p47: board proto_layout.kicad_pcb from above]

Board: 2 copper layers, 10 parts (0 on the bottom side), 11 nets, no tracks yet.

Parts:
A1: RaspberryPi_Pico; RaspberryPi_Pico_Common_SMD
D1, D2: 1N4007; D_DO-41_SOD81_P10.16mm_Horizontal
J2, J3, J4: Screw_Terminal_01x02; TerminalBlock_MaiXu_MX126-5.0-02P_1x02_P5.00mm
U2: Tauno_Oled_096_SSD1306; Tauno_OLED_ssd1306
U3, U4: Tauno_Rotary_Encoder
U6: PC817; DIP-4_W7.62mm

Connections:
+3.3V: A1.36 (3V3), U2.1 (VCC), U3.4 (+), U4.4 (+)
GND: A1.3 (GND), A1.8 (GND), A1.13 (GND), A1.18 (GND), A1.23 (GND), A1.28 (GND), A1.38 (GND), U2.2 (GND), U3.5 (GND), U4.5 (GND), U6.2
Left_RE_CLK: A1.21 (GPIO16), U3.1 (CLK)
Left_RE_DT: A1.22 (GPIO17), U3.2 (DT)
Left_RE_SW: A1.24 (GPIO18), U3.3 (SW)
unnamed: D1.2 (A), D2.1 (K)
Right_RE_CLK: A1.25 (GPIO19), U4.1 (CLK)
Right_RE_DT: A1.26 (GPIO20), U4.2 (DT)
Right_RE_SW: A1.27 (GPIO21), U4.3 (SW)
SCL: A1.7 (GPIO5), U2.3 (SCL)
SDA: A1.6 (GPIO4), U2.4 (SDA)

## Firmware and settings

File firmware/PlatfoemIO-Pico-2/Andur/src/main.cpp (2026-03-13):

/*
 * Tauno Erik
 * Hardware:
 *  -Pico 2
 *  -TOF400C/VL53L1X - can handle about 30mm to 1200mm of range distance
 * Started: 2025.09.29
 * Edited:  2026.03.13
 *
 * Links:
 * - https://arduino-pico.readthedocs.io/en/latest/platformio.html
 * - https://randomnerdtutorials.com/raspberry-pi-pico-i2c-scanner-arduino/
 * - https://github.com/pololu/vl53l1x-arduino/
 * - https://github.com/sparkfun/SparkFun_VL53L1X_Arduino_Library
 * - https://github.com/adafruit/Adafruit_VL53L0X/tree/master
 * - https://learn.adafruit.com/adafruit-vl53l0x-micro-lidar-distance-sensor-breakout/arduino-code
 * - https://github.com/gbr1/rp2040-encoder-library
 *
 * I2C0: SDA GPIOs -> GPIO0, GPIO4, GPIO8, GPIO12, GPIO16, GPIL20
 * I2C0: SCL GPIOs -> GPIO1, GPIO5, GPIO9, GPIO13, GPIO17, GPIO21
 *
 * I2C1: SDA GPIOs -> GPIO2, GPIO6, GPIO10, GPIO14, GPIO18, GPIO26
 * I2C1: SCL GPIOs -> GPIO3, GPIO7, GPIO11, GPIO15, GPIO19, GPIO27
 *
 */

#include <Arduino.h>
#include <Wire.h>
#include <SPI.h>
#include <pico/mutex.h>        // Race Condition Protection
#include "Adafruit_VL53L0X.h"  // Sensor
#include <Adafruit_GFX.h>      // OLED
#include <Adafruit_SSD1306.h>  // OLED
#include "pio_encoder.h"       // https://github.com/gbr1/rp2040-encoder-library
#include <EEPROM.h>

auto_init_mutex(my_mutex);     // Race Condition Protection

/*******************************************************************
 Constants
 *******************************************************************/
constexpr int VERSION = 260313;  // not used!
// Memory addresses:
constexpr int ADDRESS_MIN = 0;  // Rotary Encoder MIN vale
constexpr int ADDRESS_MAX = 4;  // A 32-bit integer occupies 4 bytes of memory.
// LED Colors (and pins)
constexpr int GREEN = 2;
constexpr int RED = 3;

// I2C
// SDA - GPIO4
// SCL - GPIO5
//constexpr int SENSOR_GPIO1_PIN = 6;  // Used to indicate that data is ready
constexpr int SENSOR_XSHUT_PIN = 7;  // By default it's pulled high. When the pin is pulled low, the sensor goes into shutdown mode.

// Sensor mode
typedef enum {
    MODE_DEFAULT,
    MODE_LONG_RANGE,
    MODE_HIGH_SPEED,
    MODE_HIGH_ACCURACY
} sensor_mode_t;

sensor_mode_t sensor_mode = MODE_DEFAULT;

constexpr int GREEN_LED_PIN = GREEN;
constexpr int RED_LED_PIN = RED;

// MIN (Left) Rotary Encoder
constexpr int MIN_RE_CLK_PIN = 19; // 16;
constexpr int MIN_RE_DT_PIN = 20;  // 17;
constexpr int MIN_RE_SW_PIN = 21;  // 18;

// MAX (Right) Rotary Encoder
constexpr int MAX_RE_CLK_PIN = 16; // 19;
constexpr int MAX_RE_DT_PIN = 17;  // 20;
constexpr int MAX_RE_SW_PIN = 18;  // 21;

// Signal Out
//constexpr int SIGNAL_OUT_1_PIN = 22; // Not used
constexpr int SIGNAL_OUT_2_PIN = 15;

// OLED Screen
constexpr int SCREEN_WIDTH = 128;         // px
constexpr int SCREEN_HEIGHT = 32;         // px
constexpr int OLED_RESET = -1;            // Reset pin # (or -1 if sharing Arduino reset pin)
constexpr uint8_t SCREEN_ADDRESS = 0x3C;  // 0x3D for 128x64, 0x3C for 128x32

// Rotary Encoder
constexpr int ENCODER_MIN_VALUE = 0;
constexpr int ENCODER_MAX_VALUE = 1200;    // 3000
constexpr int ENCODER_SMALLEST_RANGE = 10;
constexpr int DEBOUNCE_DELAY = 50;

// Counters
constexpr int MAX_ERRORS = 10;
constexpr int CYCLE_MAX_COUNT = 3000;  // Reset after

/*******************************************************************
 Global Variables
 *******************************************************************/
volatile uint distance = 0;
volatile int selected_value_min = 0;
volatile int selected_value_max = 0;

volatile int error_count = 0;
volatile int cycle_counter = 0;


// OLED Screen
Adafruit_SSD1306 display(SCREEN_WIDTH, SCREEN_HEIGHT, &Wire, OLED_RESET);

// Laser sensor
Adafruit_VL53L0X vl53lxx_sensor = Adafruit_VL53L0X();

// Rotary Encoders
PioEncoder min_rotary_encoder(MIN_RE_CLK_PIN);
PioEncoder max_rotary_encoder(MAX_RE_CLK_PIN);


/*******************************************************************
 Functions prototypes
 *******************************************************************/
void i2c_scanner();
void init_LED_pins();
void init_display();
void write_display(long dis, int min, int max);
void init_vl53lxx_sensor(sensor_mode_t mode);
void recover_vl53lxx_sensor();

void vl53lxx_sensor_OFF();
void vl53lxx_sensor_ON();
void init_ecoders();
void read_buttons();
void read_encoders();
void update_system_outputs(int led_color);

uint32_t read_memory(int address);
int write_memory(int address, uint32_t value);
uint32_t read_memory_min_value();
uint32_t read_memory_max_value();
int write_memory_min_value(uint32_t value);
int write_memory_max_value(uint32_t value);

int process_data(uint local_dis);
void handle_errors(int error);

void blink_builtin_led();

/*******************************************************************
 SETUP Core 0
 *******************************************************************/
void setup() {
  pinMode(LED_BUILTIN, OUTPUT);
  digitalWrite(LED_BUILTIN, HIGH);

  Serial.begin(921600); // 921600 115200
  //delay(1000);
  //Serial.println("Andur");
  // Do not change! Serial pordi lugemisega tekivad probleemid!!!
  //Wire.setSDA(2); // default 4
  //Wire.setSCL(3); // default 5

  //Wire.setClock(100000); // Standard mode 100 kHz I2C
  // Tekivad probleemid kui kasutada Fast mode
  //Wire.setClock(400000); // Fast mode 400 kHz I2C
  Wire.begin();

  //delay(3000);
  //i2c_scanner();
  
  EEPROM.begin(512);  // Allocate 512 bytes of flash)

  selected_value_min = read_memory_min_value();
  selected_value_max = read_memory_max_value();

  init_vl53lxx_sensor(sensor_mode);

  init_display();
}


/*******************************************************************
 SETUP Core 1
 *******************************************************************/
void setup1() {
  init_ecoders();
  init_LED_pins();
  // Init Signal output pin
  pinMode(SIGNAL_OUT_2_PIN,  OUTPUT);
  digitalWrite(SIGNAL_OUT_2_PIN, LOW);
}

/*******************************************************************
 Core 0 loop
 High-speed sensing and visual output
 *******************************************************************/
void loop() {
  static uint local_distace = 0;
  static uint old_local_distace = 0;
  static unsigned long last_display_time = millis();
  static unsigned long last_sensor_success = 0;

  // Sensor
  VL53L0X_RangingMeasurementData_t measure;
  vl53lxx_sensor.rangingTest(&measure, false); // pass in 'true' to get debug data printout!

  //Serial.print("measure.RangeStatus ");
  //Serial.print(measure.RangeStatus);
  //Serial.print(" D=");
  int status = measure.RangeStatus;
  if (status == 0) {
    mutex_enter_blocking(&my_mutex);
      distance = measure.RangeMilliMeter; // Global
      // Simple EMA Filter: NewValue = (alpha * CurrentReading) + (1 - alpha) * OldValue
      // Higher alpha (e.g., 0.3) = faster response, lower alpha (e.g., 0.05) = smoother
      local_distace = (uint)(0.2 * distance) + (0.8 * old_local_distace);
      //local_distace = distance;
    mutex_exit(&my_mutex);

    old_local_distace = local_distace;
    last_sensor_success = millis();
    error_count = 0;
    //error_count = process_data(local_distace); // Reset error counter on success

    cycle_counter++;
    //Serial.print("Cycle counter: ");
    //Serial.print(cycle_counter);
    //Serial.print(" : ");
    digitalWrite(LED_BUILTIN, HIGH);
  } else {
    blink_builtin_led();
    handle_errors(status);
  }

  // Restart time to time
  /*
  if (cycle_counter >= CYCLE_MAX_COUNT) {
    Serial.print("Cycle counter: ");
    Serial.println(cycle_counter);
    recover_vl53lxx_sensor();
    cycle_counter = 0;
  }
    */

  // Watchdog to reset sensor
  if (millis() - last_sensor_success > 2000) {
    recover_vl53lxx_sensor();
    cycle_counter = 0;
  }

  // Propably a error
  if (local_distace > 3000) {
    recover_vl53lxx_sensor();
    cycle_counter = 0;
  }

  // Display data ebery 300 ms
  if ((unsigned long)(millis() - last_display_time) >= 300) {
    //Serial.print("* ");
    process_data(local_distace);
    last_display_time = millis();
  }
} // loop() end



/*******************************************************************
 Core 1 loop
 *******************************************************************/
void loop1() {
  //delay(10);
  read_encoders();
  read_buttons();

  //Serial.print("min=");
  //Serial.print(selected_value_min);
  //Serial.print("\tmax=");
  //Serial.print(selected_value_max);
  //Serial.print("\n");
  update_system_outputs(RED); // RED or GREEN LED
}


/******************************************************************
 Scanns connected I2C devices
 and prints addresses.
 ******************************************************************/
void i2c_scanner() {
  byte error, address;
  int nDevices = 0;
  Serial.println("Scanning I2C ...");

  for(address = 1; address < 127; address++ ) {
    Wire.beginTransmission(address);
    //delay(1);
    error = Wire.endTransmission();
    //delay(1);
    if (error == 0) {
      Serial.print("I2C device found at address 0x");
      if (address<16) {
        Serial.print("0");
      }
      Serial.println(address,HEX);
      nDevices++;
    }
    else if (error==4) {
      Serial.print("Unknow error at address 0x");
      if (address<16) {
        Serial.print("0");
      }
      Serial.println(address,HEX);
    }    
  }
  if (nDevices == 0) {
    Serial.println("No I2C devices found\n");
  }
  else {
    Serial.println("done\n");
  }
  delay(5000);
}


/*******************************************************************
 Initialises Green and Red LED pins.
 *******************************************************************/
void init_LED_pins() {
  pinMode(GREEN_LED_PIN, OUTPUT);
  pinMode(RED_LED_PIN, OUTPUT);

  digitalWrite(RED_LED_PIN, LOW);
  digitalWrite(GREEN_LED_PIN, LOW);
}


/*******************************************************************
 Initialises OLED screen.
 *******************************************************************/
void init_display() {
  Serial.print(F("SSD1306 init: "));
   // SSD1306_SWITCHCAPVCC = generate display voltage from 3.3V internally
   // SSD1306_EXTERNALVCC
  if(!display.begin(SSD1306_SWITCHCAPVCC, SCREEN_ADDRESS)) {
    Serial.println(F("SSD1306 allocation failed"));
    while (1) {
      Serial.println("Err 1");
      delay(500);
    }
  }
  Serial.println("SSD1306 OK!");
  
  mutex_enter_blocking(&my_mutex);
    uint local_distace = distance;
  mutex_exit(&my_mutex);

  display.setRotation(2);  // rotates text on OLED 1=90 degrees, 2=180 degrees

  write_display(local_distace, selected_value_min, selected_value_max);
}


/*****************************************************************
 @param dis - distance
 @param min - selected_value_min
 @param max - selected_value_max
 *****************************************************************/
void write_display(long dis, int min, int max) {
  display.clearDisplay();
  //display.setRotation(2); //rotates text on OLED 1=90 degrees, 2=180 degrees
  display.setTextSize(2);
  display.setTextColor(SSD1306_WHITE);

  display.setCursor(10,0);

  display.print(dis);
  display.println(F(" mm"));

  display.setTextSize(1);
  display.setTextColor(SSD1306_WHITE);

  display.setCursor(10, 20);

  display.print(F("min:"));
  display.print(min);

  display.setCursor(50, 20);

  display.print(F("  max:"));
  display.print(max);

  display.display();  // Update display
}


/*******************************************************************
 Initialises TOF sensor
 VL53Lxx-v2
 *******************************************************************/
void init_vl53lxx_sensor(sensor_mode_t mode) {
  Serial.print("Init VL53L0X sensor: ");

  // Shutdown pin
  pinMode(SENSOR_XSHUT_PIN, OUTPUT);
  pinMode(SENSOR_XSHUT_PIN, INPUT_PULLUP);

  while (!vl53lxx_sensor.begin()) {
    Serial.println(F("VL53L0X sensor failed!"));

    vl53lxx_sensor_OFF();
    delay(100);
    vl53lxx_sensor_ON();
    delay(100);
  }

  // Adafruit_VL53L0X::VL53L0X_SENSE_DEFAULT
  // Adafruit_VL53L0X::VL53L0X_SENSE_LONG_RANGE
  // Adafruit_VL53L0X::VL53L0X_SENSE_HIGH_SPEED
  // Adafruit_VL53L0X::VL53L0X_SENSE_HIGH_ACCURACY
  switch (mode) {
    case MODE_DEFAULT:
      vl53lxx_sensor.configSensor(Adafruit_VL53L0X::VL53L0X_SENSE_DEFAULT);
      break;
    case MODE_LONG_RANGE:
      vl53lxx_sensor.configSensor(Adafruit_VL53L0X::VL53L0X_SENSE_LONG_RANGE);
      break;
    case MODE_HIGH_SPEED:
      vl53lxx_sensor.configSensor(Adafruit_VL53L0X::VL53L0X_SENSE_HIGH_SPEED);
      break;
    case MODE_HIGH_ACCURACY:
      vl53lxx_sensor.configSensor(Adafruit_VL53L0X::VL53L0X_SENSE_HIGH_ACCURACY);
      break;
    default:
      vl53lxx_sensor.configSensor(Adafruit_VL53L0X::VL53L0X_SENSE_DEFAULT);
      break;
  }

  Serial.println("VL53L0X OK!");
}

/*******************************************************************
 OFF (shutdown mode)
 *******************************************************************/
void vl53lxx_sensor_OFF() {
  digitalWrite(SENSOR_XSHUT_PIN, LOW);
}

/*******************************************************************
 ON
 *******************************************************************/
void vl53lxx_sensor_ON() {
  digitalWrite(SENSOR_XSHUT_PIN, HIGH);
}

/*******************************************************************
 *******************************************************************/
void init_ecoders() {
  min_rotary_encoder.begin();
  min_rotary_encoder.flip();

  max_rotary_encoder.begin();
  max_rotary_encoder.flip();
  // Buttons
  pinMode(MIN_RE_SW_PIN, INPUT_PULLUP);
  pinMode(MAX_RE_SW_PIN, INPUT_PULLUP);

}

/*******************************************************************
 Read Rotary Encoder buttons
 *******************************************************************/
void read_buttons() {
  static int min_btn_state = LOW;
  static int max_btn_state = LOW;
  static int last_min_btn_state = HIGH;
  static int last_max_btn_state = HIGH;

  static unsigned long last_min_time = 0;
  static unsigned long last_max_time = 0;

  // 1. Read
  int min_reading = digitalRead(MIN_RE_SW_PIN);
  int max_reading = digitalRead(MAX_RE_SW_PIN);

  // 2. Is  state changed
  if (min_reading != last_min_btn_state) {
    last_min_time = millis();
  }
  if (max_reading != last_max_btn_state) {
    last_max_time = millis();
  }

  // 3. if time has passed
  if ((millis() - last_min_time) > DEBOUNCE_DELAY) {
    // 4. button state has actually changed
    if (min_reading != min_btn_state) {
      min_btn_state = min_reading;
      // 5.
      if (min_btn_state == LOW) {
        // Serial.println("----MIN");
        // Save MIN value
        write_memory_min_value(selected_value_min);
      }
    }
  }
  last_min_btn_state = min_reading;

  // 3. if time has passed
  if ((millis() - last_max_time) > DEBOUNCE_DELAY) {
    // 4. button state has actually changed
    if (max_reading != max_btn_state) {
      max_btn_state = max_reading;
      // 5.
      if (max_btn_state == LOW) {
        // Serial.println("++++MAX");
        // Save MAX value
        write_memory_max_value(selected_value_max);
      }
    }
  }
  last_max_btn_state = max_reading;
}


/*******************************************************************
 Read Min and Max rotary encoder values
 *******************************************************************/
void read_encoders() {
  static int old_max_encoder_count = 0;
  static int old_min_encoder_count = 0;
  // Rotary Encoder lugemid
  // - kui ei keera on 0
  int new_min_encoder_count = min_rotary_encoder.getCount();
  int new_max_encoder_count = max_rotary_encoder.getCount();

  // MIN
  if (new_min_encoder_count > old_min_encoder_count) {
    mutex_enter_blocking(&my_mutex); // Race Condition Protection
      selected_value_min++;
      if (selected_value_min < ENCODER_MIN_VALUE) {
        selected_value_min = ENCODER_MIN_VALUE;
      } else if (selected_value_min > ENCODER_MAX_VALUE) {
        selected_value_min = ENCODER_MAX_VALUE;
      }
      // et ei oleks suurem, kui max
      if (selected_value_min >= selected_value_max) {
        selected_value_min = selected_value_max - ENCODER_SMALLEST_RANGE;
      }
    mutex_exit(&my_mutex);
  }
  else if (new_min_encoder_count < old_min_encoder_count) {
    mutex_enter_blocking(&my_mutex); // Race Condition Protection
      selected_value_min--;
      if (selected_value_min < ENCODER_MIN_VALUE) {
        selected_value_min = ENCODER_MIN_VALUE;
      } else if (selected_value_min > ENCODER_MAX_VALUE) {
        selected_value_min = ENCODER_MAX_VALUE;
      }
    mutex_exit(&my_mutex);
  }

  // MAX
  if (new_max_encoder_count > old_max_encoder_count) {
    mutex_enter_blocking(&my_mutex); // Race Condition Protection
      selected_value_max++;
      if (selected_value_max < ENCODER_MIN_VALUE) {
        selected_value_max = ENCODER_MIN_VALUE;
      } else if (selected_value_max > ENCODER_MAX_VALUE) {
        selected_value_max = ENCODER_MAX_VALUE;
      }
    mutex_exit(&my_mutex);
  }
  else if (new_max_encoder_count < old_max_encoder_count) {
    mutex_enter_blocking(&my_mutex); // Race Condition Protection
      selected_value_max--;
      if (selected_value_max < ENCODER_MIN_VALUE) {
        selected_value_max = ENCODER_MIN_VALUE;
      } else if (selected_value_max > ENCODER_MAX_VALUE) {
        selected_value_max = ENCODER_MAX_VALUE;
      }
      // Et ei oleks väiksem, kui MIN
      if (selected_value_max <= selected_value_min) {
        selected_value_max = selected_value_min + ENCODER_SMALLEST_RANGE;
      }
    mutex_exit(&my_mutex);
  }

  old_min_encoder_count = new_min_encoder_count;
  old_max_encoder_count = new_max_encoder_count;
}


/*******************************************************************
 Set Signal Output and Staus LED:
 @param color - Select RED or GREEN color if in min/max range.
 *******************************************************************/
void update_system_outputs(int led_color) {
  mutex_enter_blocking(&my_mutex);
   uint local_distace = distance;
  mutex_exit(&my_mutex);

  bool in_range = (local_distace > selected_value_min && local_distace < selected_value_max);

  // Signal Output
  digitalWrite(SIGNAL_OUT_2_PIN, in_range ? HIGH : LOW);

  // LED Logic
  if (led_color == RED) {
    digitalWrite(GREEN_LED_PIN, in_range ? HIGH : LOW);
    digitalWrite(RED_LED_PIN, in_range ? LOW : HIGH);
  } else {
    digitalWrite(GREEN_LED_PIN, in_range ? LOW : HIGH);
    digitalWrite(RED_LED_PIN, in_range ? HIGH : LOW);
  }
}


/*******************************************************************
 @param address  - Memory address to start read
 *******************************************************************/
uint32_t read_memory(int address) {
  uint32_t value = 0;
  EEPROM.get(address, value);
  return value;
}


/*******************************************************************
 @param address  - Memory address to start write
 @param value - A 32-bit integer to write
 *******************************************************************/
int write_memory(int address, uint32_t value) {
  EEPROM.put(address, value);
  // Must commit to save to physical Flash!
  if (EEPROM.commit()) {
    return 0; // OK
  } else {
    return 1; // Error
  }
}


/*******************************************************************
 *******************************************************************/
uint32_t read_memory_min_value() {
  uint32_t value = read_memory(ADDRESS_MIN);
  return value;
}


/*******************************************************************
 *******************************************************************/
uint32_t read_memory_max_value() {
  uint32_t value = read_memory(ADDRESS_MAX);
  return value;
}


/*******************************************************************
 *******************************************************************/
int write_memory_min_value(uint32_t value) {
  int msg = 0;
  // If is a new value then write to memeory
  if (read_memory_min_value() != value) {
    msg = write_memory(ADDRESS_MIN, value);
  }
  return msg;
}


/*******************************************************************
 *******************************************************************/
int write_memory_max_value(uint32_t value) {
  int msg = 0;
  // If is a new value then write to memeory
  if (read_memory_max_value() != value) {
    msg = write_memory(ADDRESS_MAX, value);
  }
  return msg;
}


/*******************************************************************
 Reset vl53lxx sensor
 *******************************************************************/
void recover_vl53lxx_sensor() {
  int delay_val = 70;
  Serial.println("Resetting sensor...");
  
  // 1. Hardware Reset: Pull XSHUT low to shut down the sensor
  vl53lxx_sensor_OFF(); 
  delay(delay_val); // Give it time to fully discharge
  
  // 2. Power back on
  vl53lxx_sensor_ON();
  delay(delay_val); // Wait for the sensor to boot
  
  // 3. Re-initialize the library
  if (!vl53lxx_sensor.begin()) {
    Serial.println("Critical Failure: Sensor could not restart.");
  } else {
    Serial.println("Sensor recovered successfully.");
  }
}
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

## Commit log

2025-11-16 kicad update
    [Pi_Pico_Andur.kicad_pcb, Pi_Pico_Andur.kicad_sch]
2025-11-19 3d models
    [OLED_IIC_096.step, Pi_Pico_Andur.kicad_pcb, Rotary-Encoder.step]
2025-11-23 kicad files
    [pcb.kicad_pcb, pcb.kicad_sch, power.step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]
2025-12-12 uus library
    [Anduri_karp.SLDASM, andur_alumine.DXF, andur_esi.DXF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]
2026-01-08 Karp v2
    [Anduri_karp.SLDASM, KOOS.SLDASM, KOOS_v2.SLDASM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]
2026-01-14 box ver 2
    [KOOS_v2.SLDASM, v2_alusraam.DXF, v2_külg_lühem.DXF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]
2026-01-20 4mm ja anduri mudel
    [KOOS_v2.SLDASM, v2_Anduri_karp.SLDASM, v2_alusraam.DXF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]
2026-01-20 uued dxfid
    [KOOS_v2.SLDASM, v2_pleks.DXF, v2_pleks.SLDPRT]
